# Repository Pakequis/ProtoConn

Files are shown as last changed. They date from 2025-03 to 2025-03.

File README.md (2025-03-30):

[][cc-by-sa]
# ProtoConn
A prototype board with connectors for electronic testing and development

This work is licensed under a
[Creative Commons Attribution-ShareAlike 4.0 International License][cc-by-sa].

[][cc-by-sa]

[cc-by-sa]: http://creativecommons.org/licenses/by-sa/4.0/
[cc-by-sa-image]: https://licensebuttons.net/l/by-sa/4.0/88x31.png
[cc-by-sa-shield]: https://img.shields.io/badge/License-CC%20BY--SA%204.0-lightgrey.svg

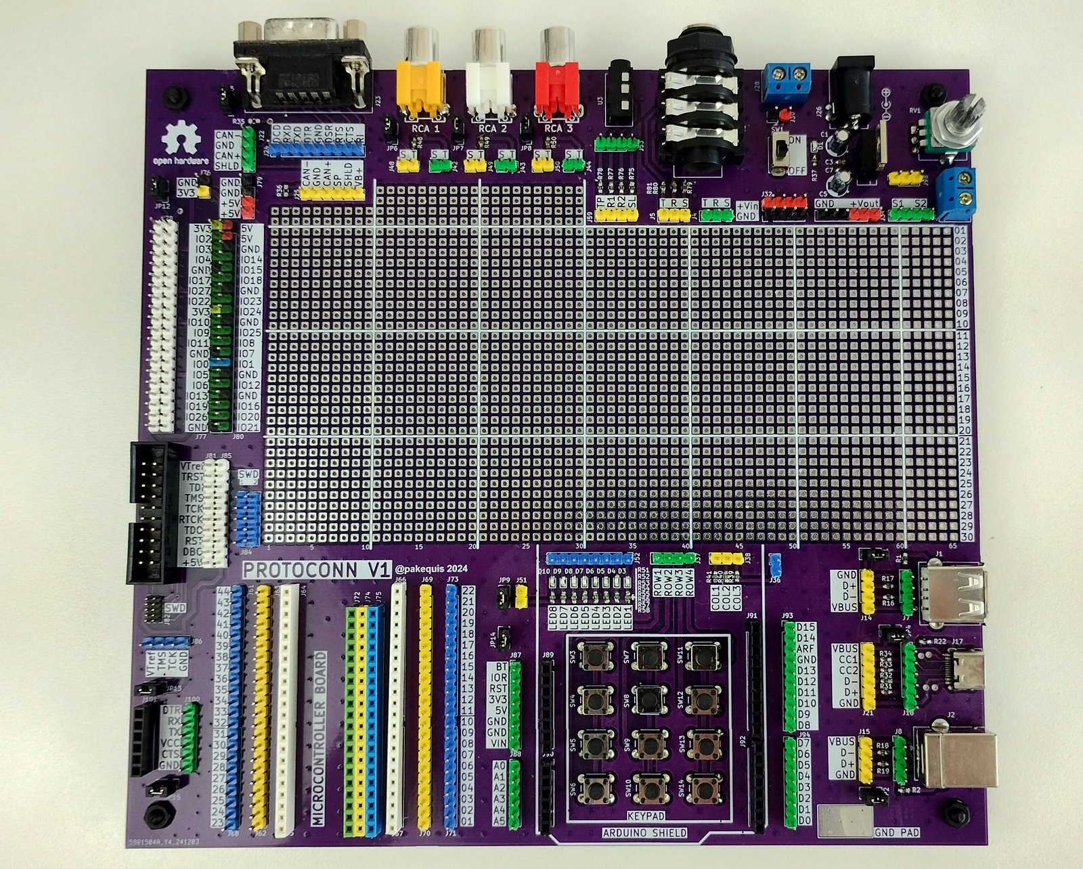
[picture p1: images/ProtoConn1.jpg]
ProtoConn V1


### Overview

This open-hardware prototype board was created as a practical tool to simplify and speed up prototyping. With connectors for various functions, it’s designed to make development more flexible and efficient.

## Demo video:
Demo Video (https://www.youtube.com/watch?v=2lRD86RqEf8)

### Features

Size: 200 x 195 mm dual layer PCB.
- **DE-9 Connector**: Supports serial, joystick, or CAN communication.
- **RCA Connectors**: Includes 3 RCA connectors.
- **Audio Connectors**:
  - 1 P2 audio jack (up to 4 pins).
  - 1 6.3 mm audio jack.
- **Screw Terminals**: Includes 2 screw terminals, one dedicated to power supply.
- **Barrel Connector**: For power input, with integrated 78XX voltage regulator and on/off switch.
- **Potentiometer or Rotary Encoder**: For adjustable input functionality.
- **40-Pin I/O Connector**: Compatible with Raspberry Pi and other Single Board Computers (SBCs).
- **JTAG Connector**: Standard 20-pin JTAG interface.
- **SWD Connectors**:
  - 10-pin SWD with 2.54 mm pitch.
  - 10-pin SWD with 1.27 mm pitch.
- **Programming Connector**: 4-pin interface for STM32 programming.
- **USB/Serial Converter Connector**: Simplifies communication setup.
- **Microcontroller Spaces**: Dedicated spaces for microcontroller boards with widths of 600, 700, 800, and 1000 mils.
- **Arduino Shield Compatibility**: Area for connecting Arduino-compatible shields.
- **Matrix Keypad**: Includes a 12-key matrix keypad.
- **LED Indicators**: 8 LEDs with current-limiting resistors.
- **USB Connectors**:
  - 1 USB Type-A connector.
  - 1 USB Type-B connector.
  - 1 USB Type-C connector.
- **Ground Pad**: Convenient GND pad for prototyping needs.

### Project Files
All project files are organized in the `hardware` folder. If you'd like to manufacture an identical board, the Gerber files necessary for production are available in the `hardware/fab` folder.

Please note that the board does not need to be assembled exactly as shown in the photo. You are free to assemble only the components you want or need, tailoring it to your specific requirements.

Because of this flexibility, the project does not include a complete bill of materials (BOM). Please refer to the notes in the schematic diagram for more detailed information.

Below is an example of an assembled board featuring common black connectors:

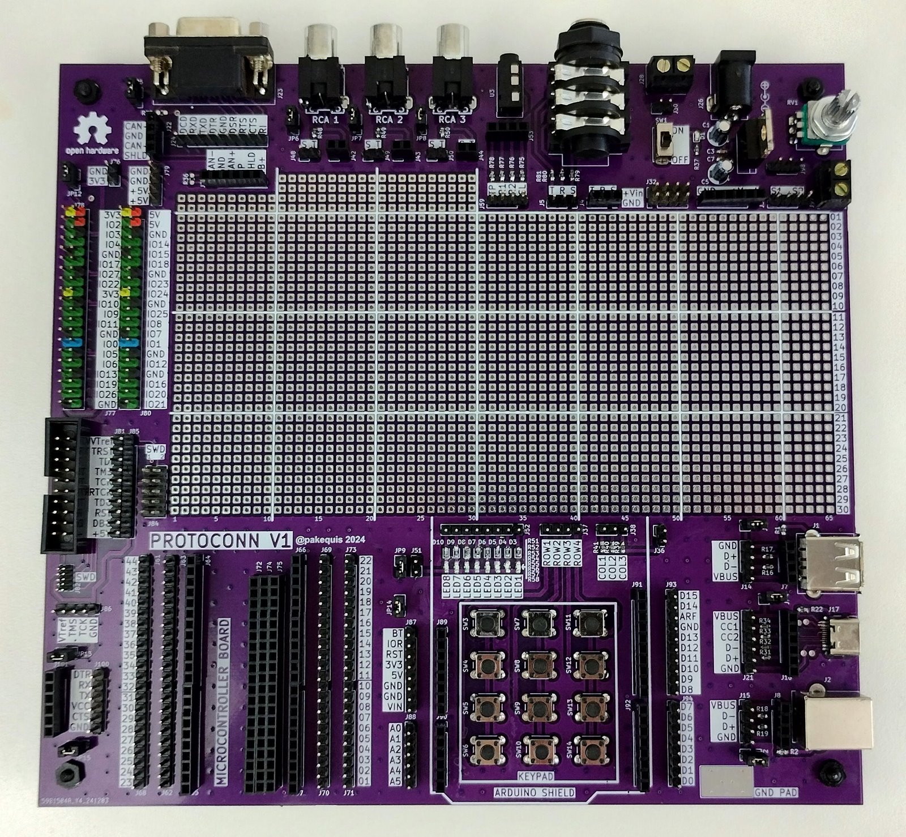
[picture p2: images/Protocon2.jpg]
Photo of the board with black connectors


## Recommended Components

Here are some specific components that can be used with this board, along with links to purchase them:

- **Colorful Breakable Pin Header 2.54mm Single Row Male**: [Aliexpress](https://s.click.aliexpress.com/e/_op1UJvb)
- **Colorful Breakable Pin Header 2.54mm Single Row Female**: [Aliexpress](https://s.click.aliexpress.com/e/_oB8GhPJ)
- **40-Pin Header for Raspberry Pi**: [Aliexpress](https://s.click.aliexpress.com/e/_oCoQNaN)
- **USB Type-C 02 Connector**: [Aliexpress](https://s.click.aliexpress.com/e/_oo63JmH)
- **Power switch**: [Aliexpress](https://s.click.aliexpress.com/e/_oD5kKvX)

The other components are common and easy to find.

**Affiliate Disclosure**: Some of the links provided in this section are affiliate links. This means that I may earn a commission if you make a purchase through these links, at no additional cost to you. Your support helps to maintain and improve this project.

### Connector Areas

Below are images showcasing the connector areas of the board:

### Top Connector Area
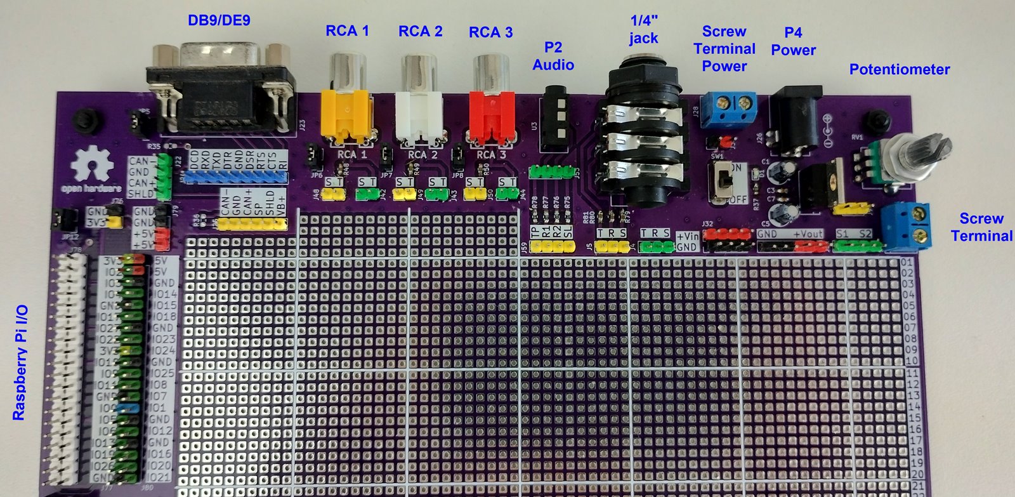
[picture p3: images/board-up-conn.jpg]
Photo of the top connector area


### Bottom Connector Area
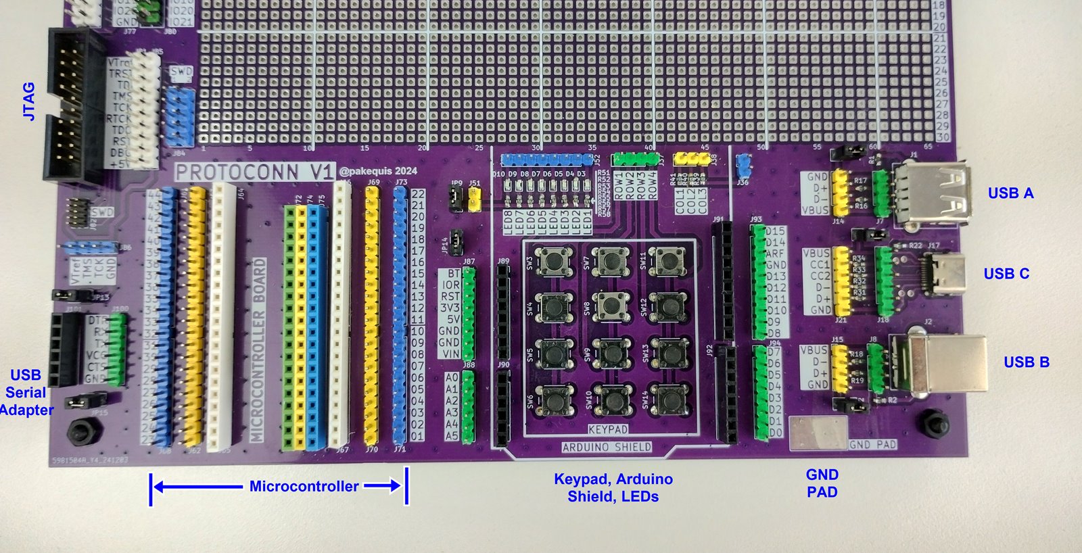
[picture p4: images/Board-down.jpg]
Photo of the bottom connector area


### Project Background:
Almost 20 years ago, I purchased a commercial prototype board with multiple connectors that greatly facilitated my work. Unfortunately, I no longer remember where I bought it, and I am unsure if it is still being manufactured. This inspired me to create my own version, customized to meet my specific needs.

The board (circa 2008):
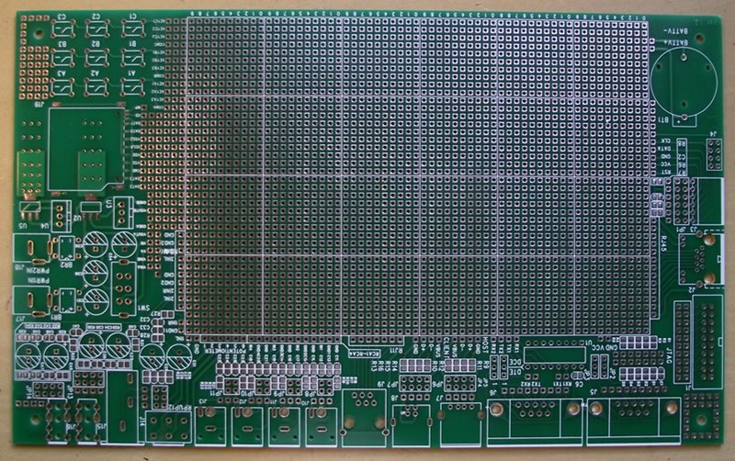
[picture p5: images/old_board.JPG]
Photo of the original commercial board


## Contact:

Feel free to reach out to me on social media: @pakequis in any of them...

You can also send me an email at pakequis (Gmail).

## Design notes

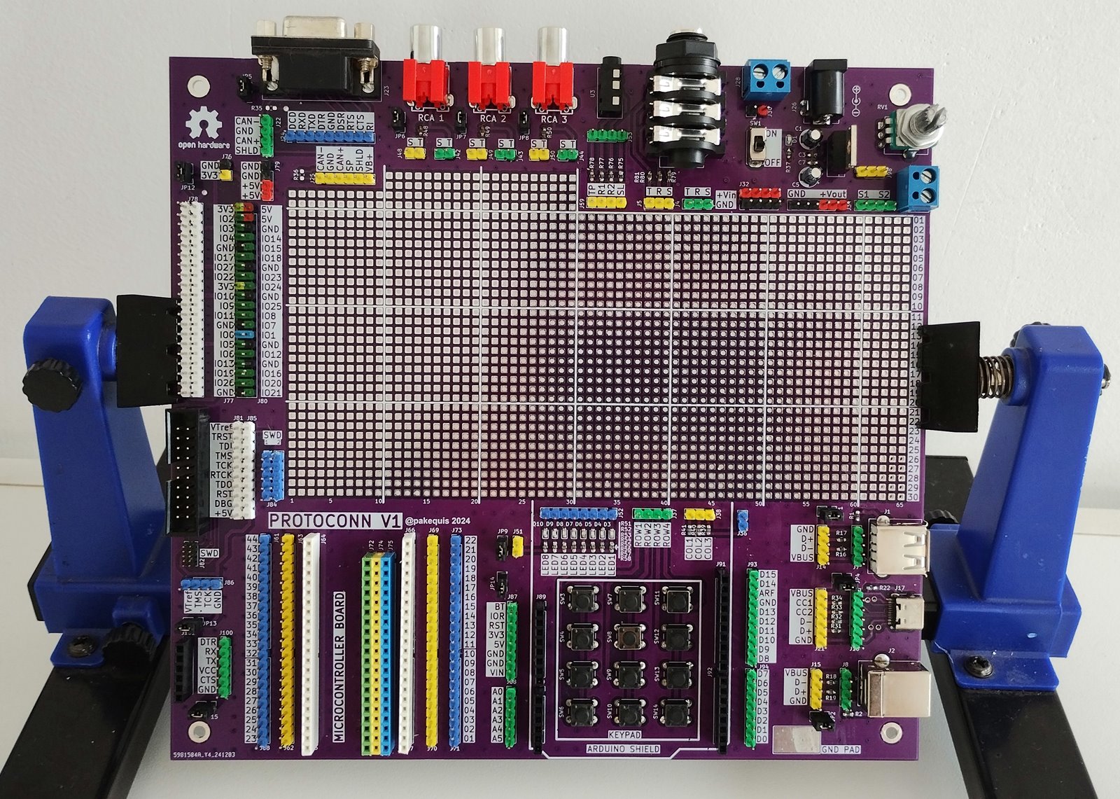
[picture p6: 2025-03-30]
images/Protoconn_V1.jpg

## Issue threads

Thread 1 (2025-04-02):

Soldering jig for ProtoConn

shreekumar3d, 2025-04-02:
I have created a [tool that generates soldering jigs](https://github.com/shreekumar3d/jigita) directly from KiCAD files. As a test for my tool, I ran it against ProtoConn PCB design and got good initial results.  The tool creates this workflow:

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

The orange part is the jig (3D printable design). With the jig in hand, you first insert the components into the holders in the jig. Then you insert the PCB, and solder the components. Then you pull out the assembled PCB.  I have documented this a bit more [at this page](https://github.com/shreekumar3d/jigita/tree/main/demo/06-lots-of-connectors). There you'll find the jig and a FreeCAD test file as well.

Hoping you may find the tool useful.  It probably needs some tweaks to make it usable. Comments welcome; happy to answer any queries.

Pakequis, 2025-04-03:
Thanks a lot for pitching in and helping out with this project! I'm really grateful for your contribution. In the next update of the README, I'll make sure to add a link to this project. Thanks again for your support!

Closed 2025-04-03.

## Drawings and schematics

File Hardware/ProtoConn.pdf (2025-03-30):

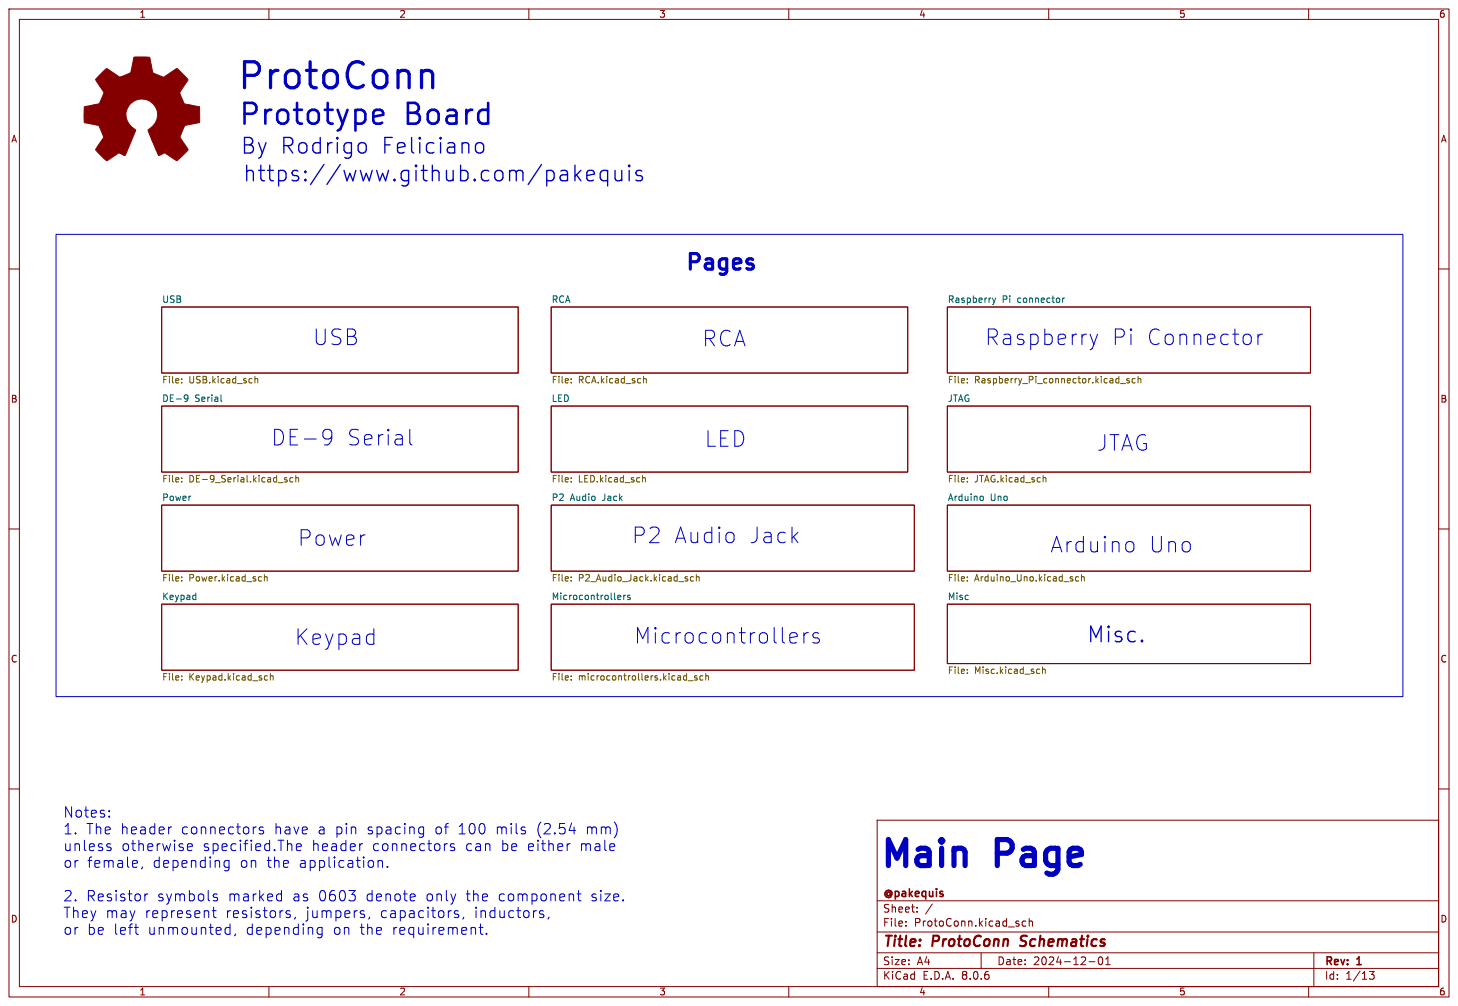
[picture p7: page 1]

ProtoConn
By Rodrigo Feliciano
https://www.github.com/pakequis

File: USB.kicad_sch Keypad File: Keypad.kicad_sch

Notes:
or female, depending on the application.

Id: 1/13 Title: ProtoConn Schematics

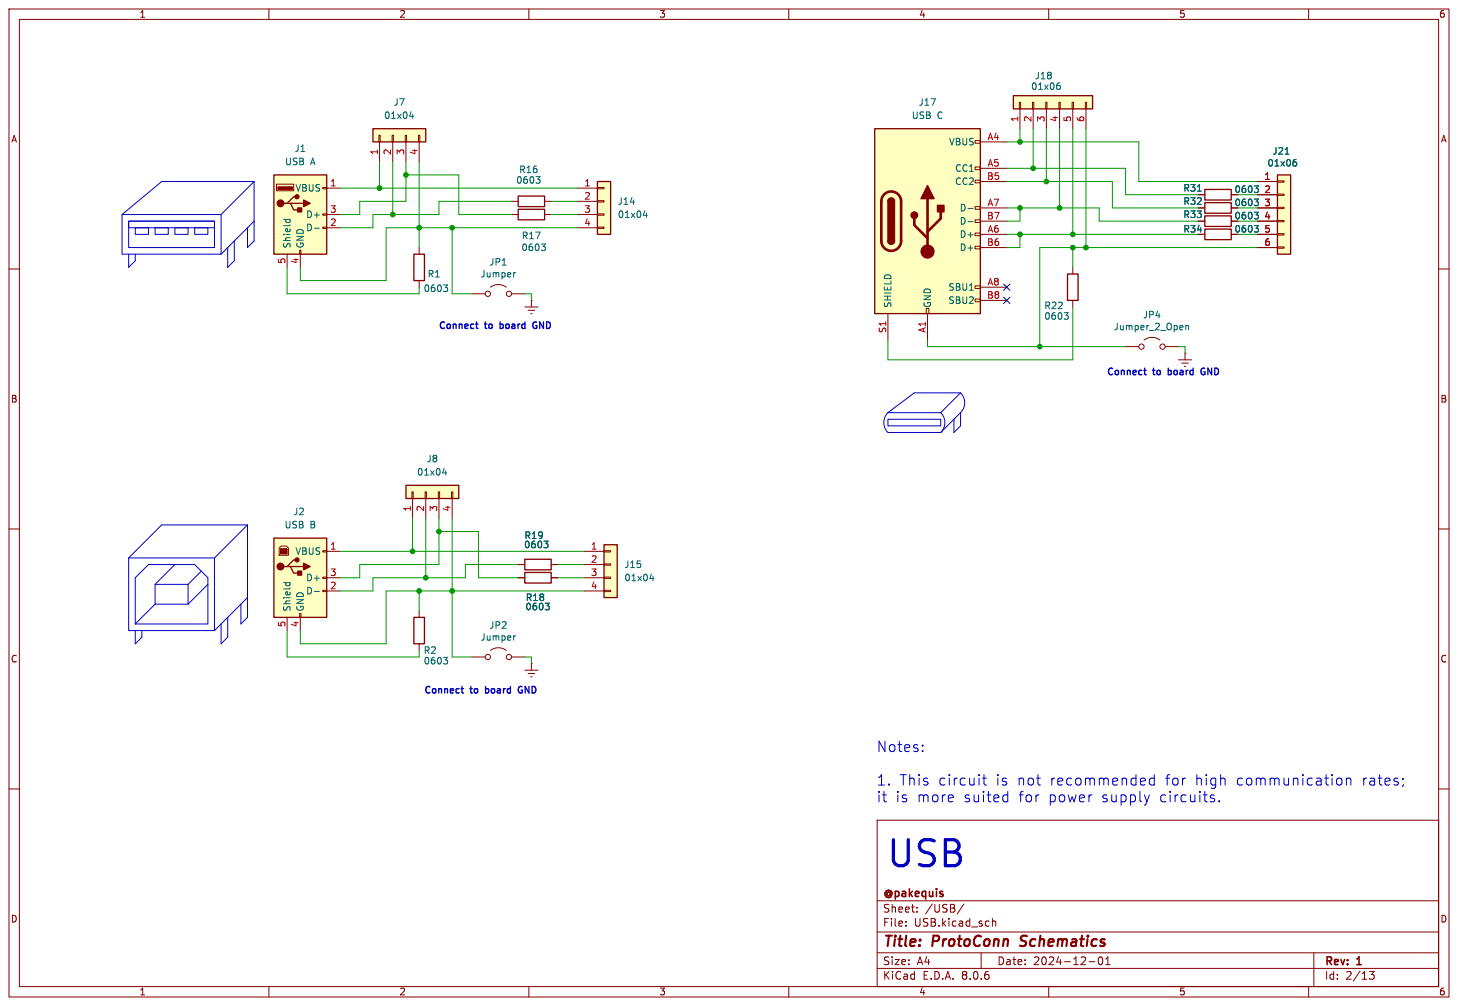
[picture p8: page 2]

Connect to board GND

File: USB.kicad_sch Sheet: /USB/ @pakequis

Id: 2/13 Title: ProtoConn Schematics

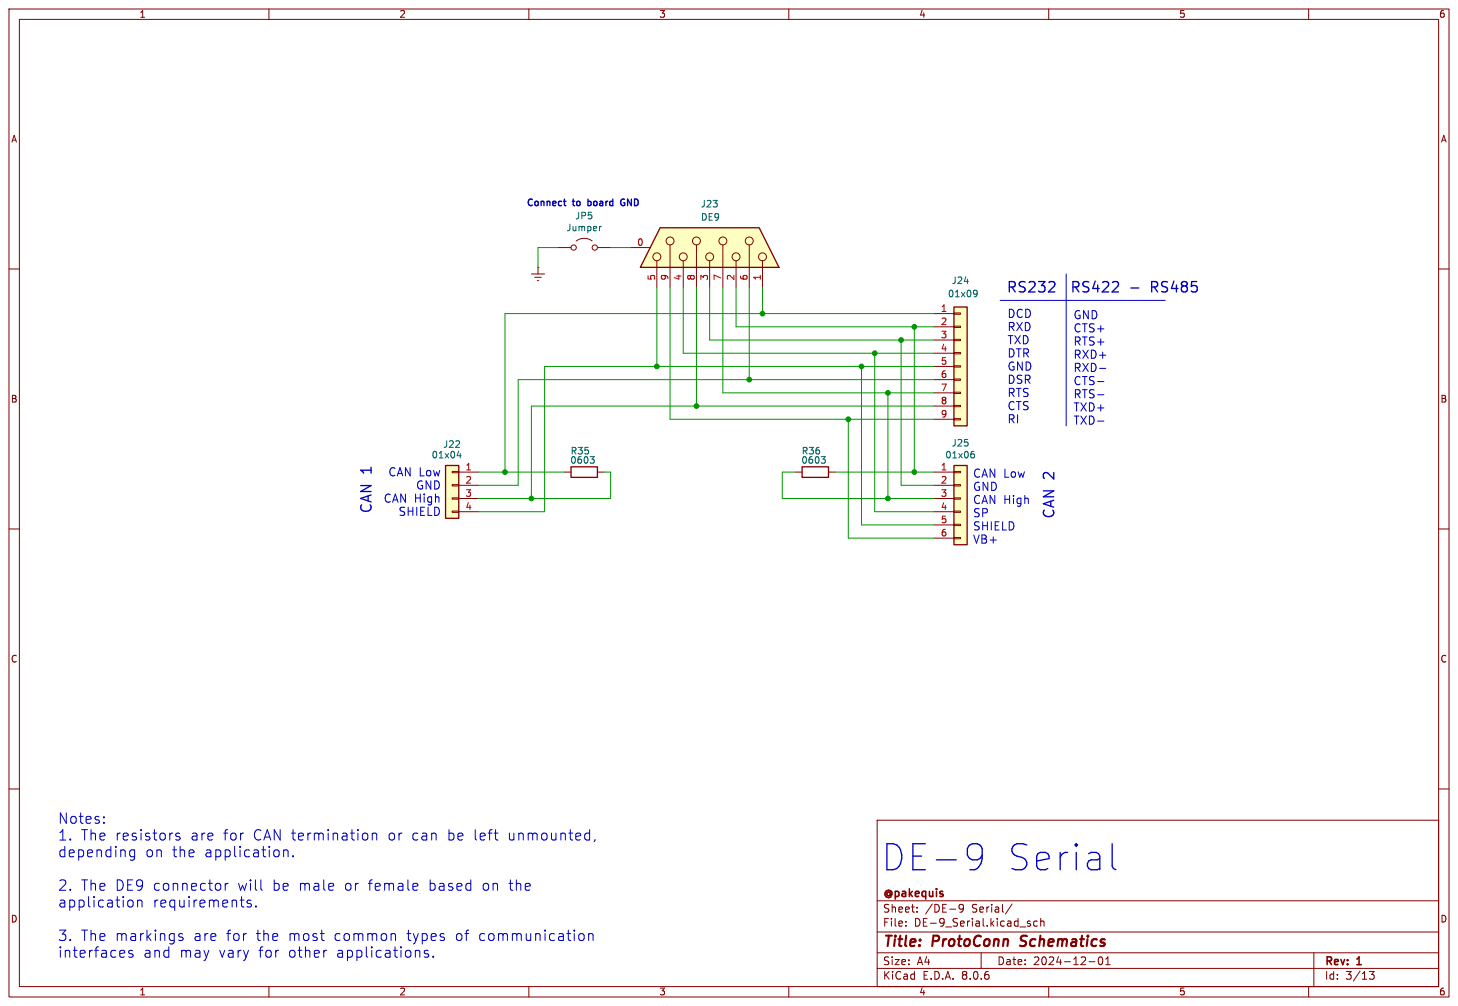
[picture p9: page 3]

RTS- TXD+ TXD- DE-9 Serial

CTS+
RTS+ RXD+ RXD- CTS-

Id: 3/13 Title: ProtoConn Schematics

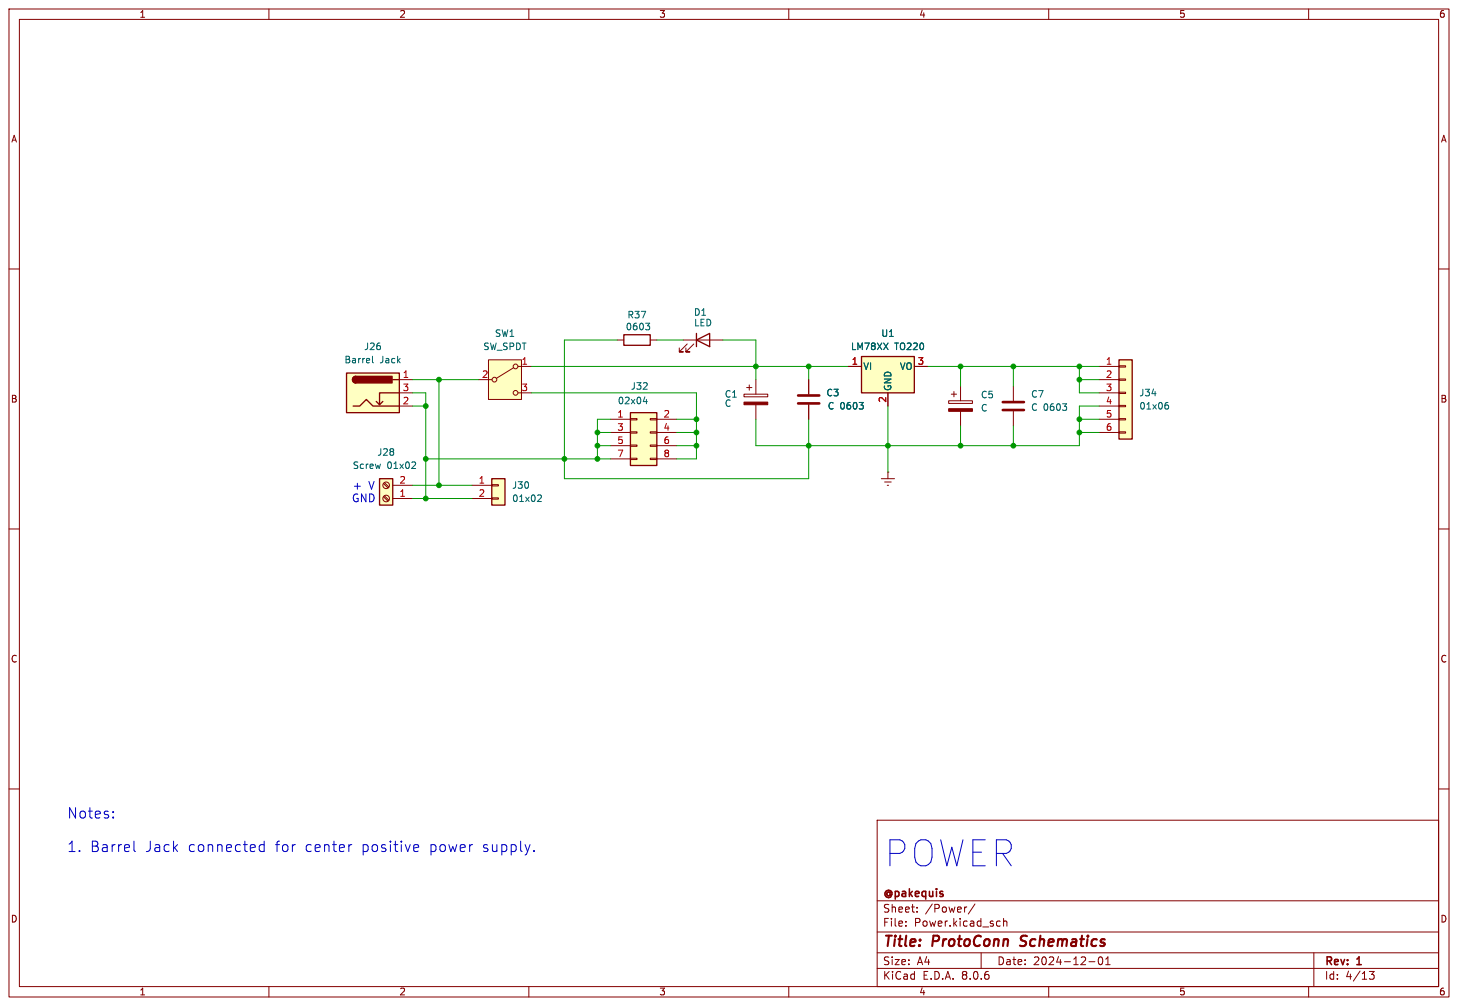
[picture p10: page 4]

File: Power.kicad_sch Sheet: /Power/ @pakequis

Id: 4/13 Title: ProtoConn Schematics

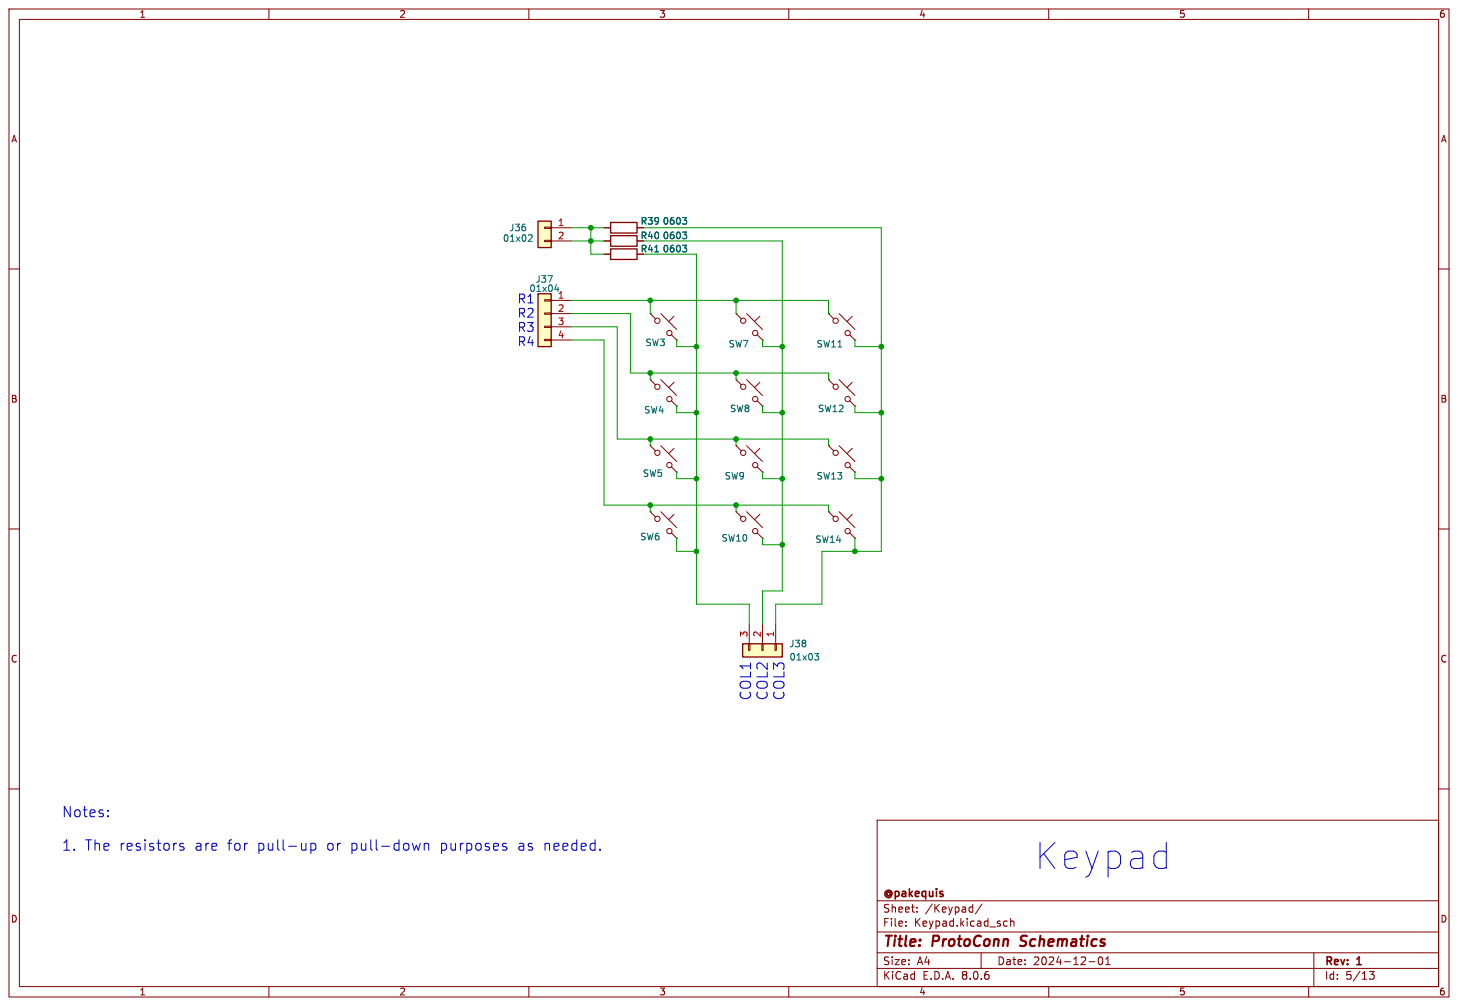
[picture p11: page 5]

@pakequis
File: Keypad.kicad_sch Sheet: /Keypad/
Id: 5/13 Title: ProtoConn Schematics

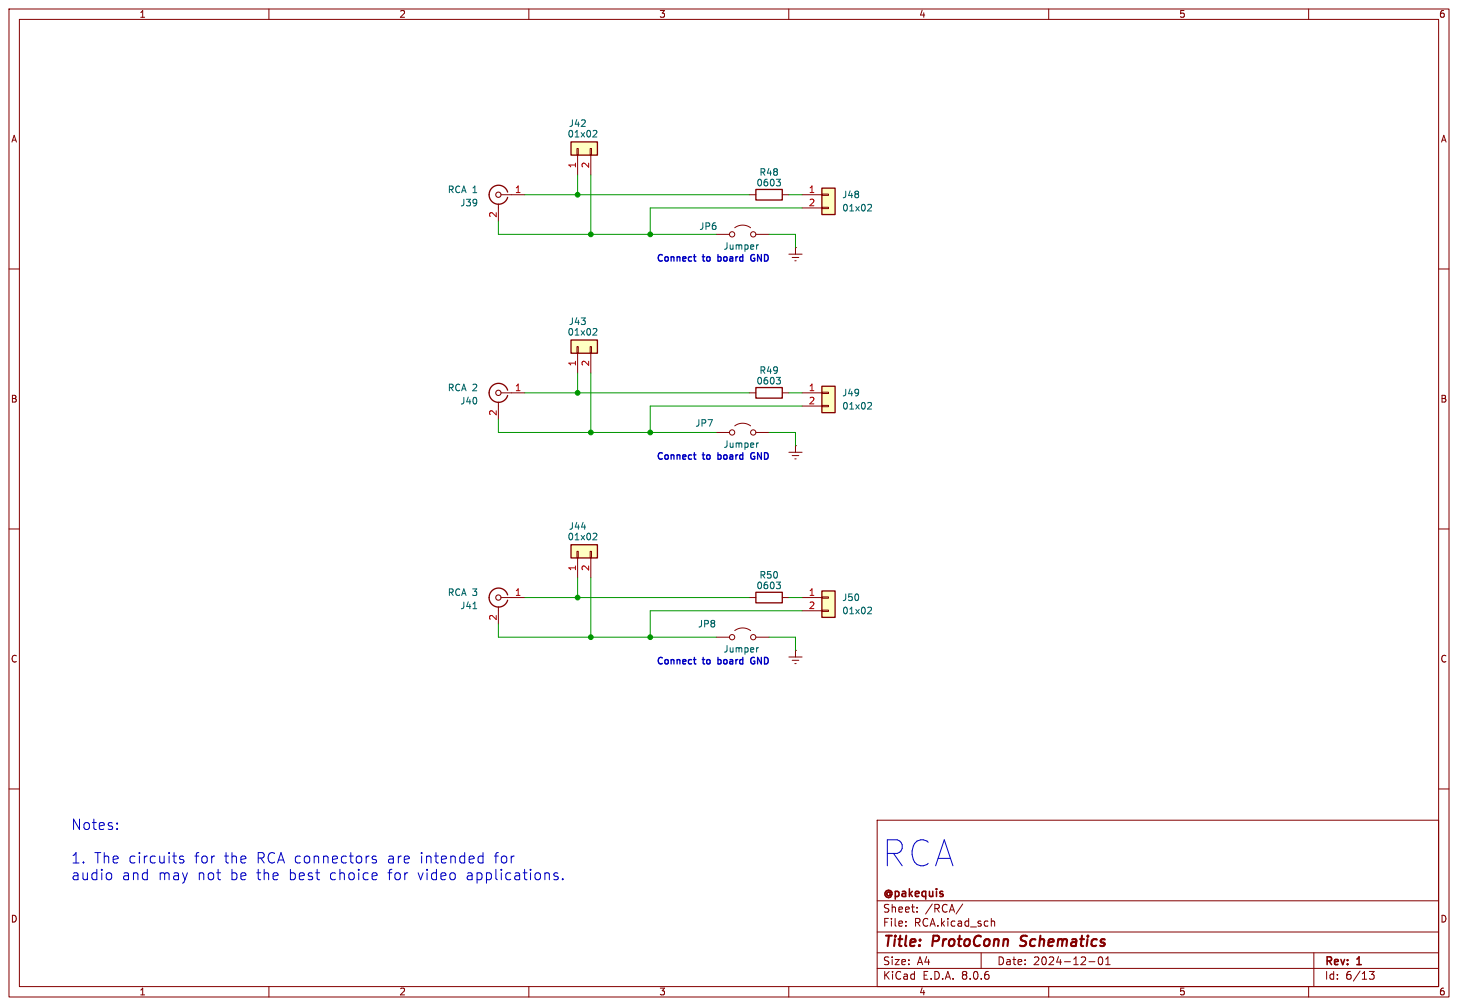
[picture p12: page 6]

Connect to board GND

Connect to board GND Notes:

File: RCA.kicad_sch Sheet: /RCA/ @pakequis

Id: 6/13 Title: ProtoConn Schematics

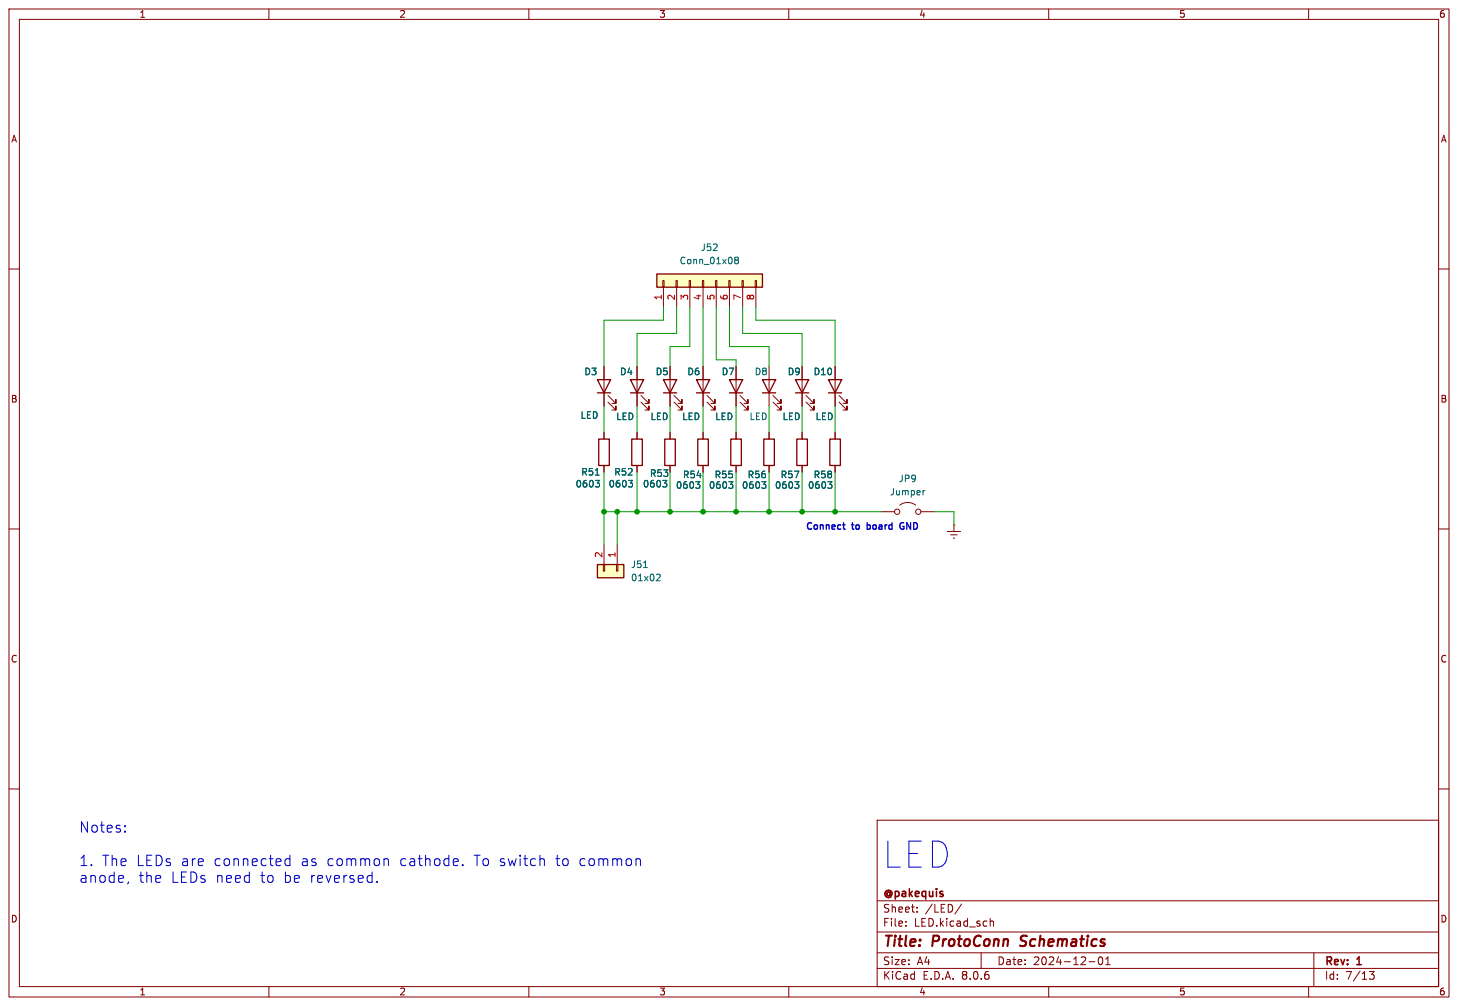
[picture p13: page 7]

Connect to board GND

File: LED.kicad_sch Sheet: /LED/ @pakequis

Id: 7/13 Title: ProtoConn Schematics

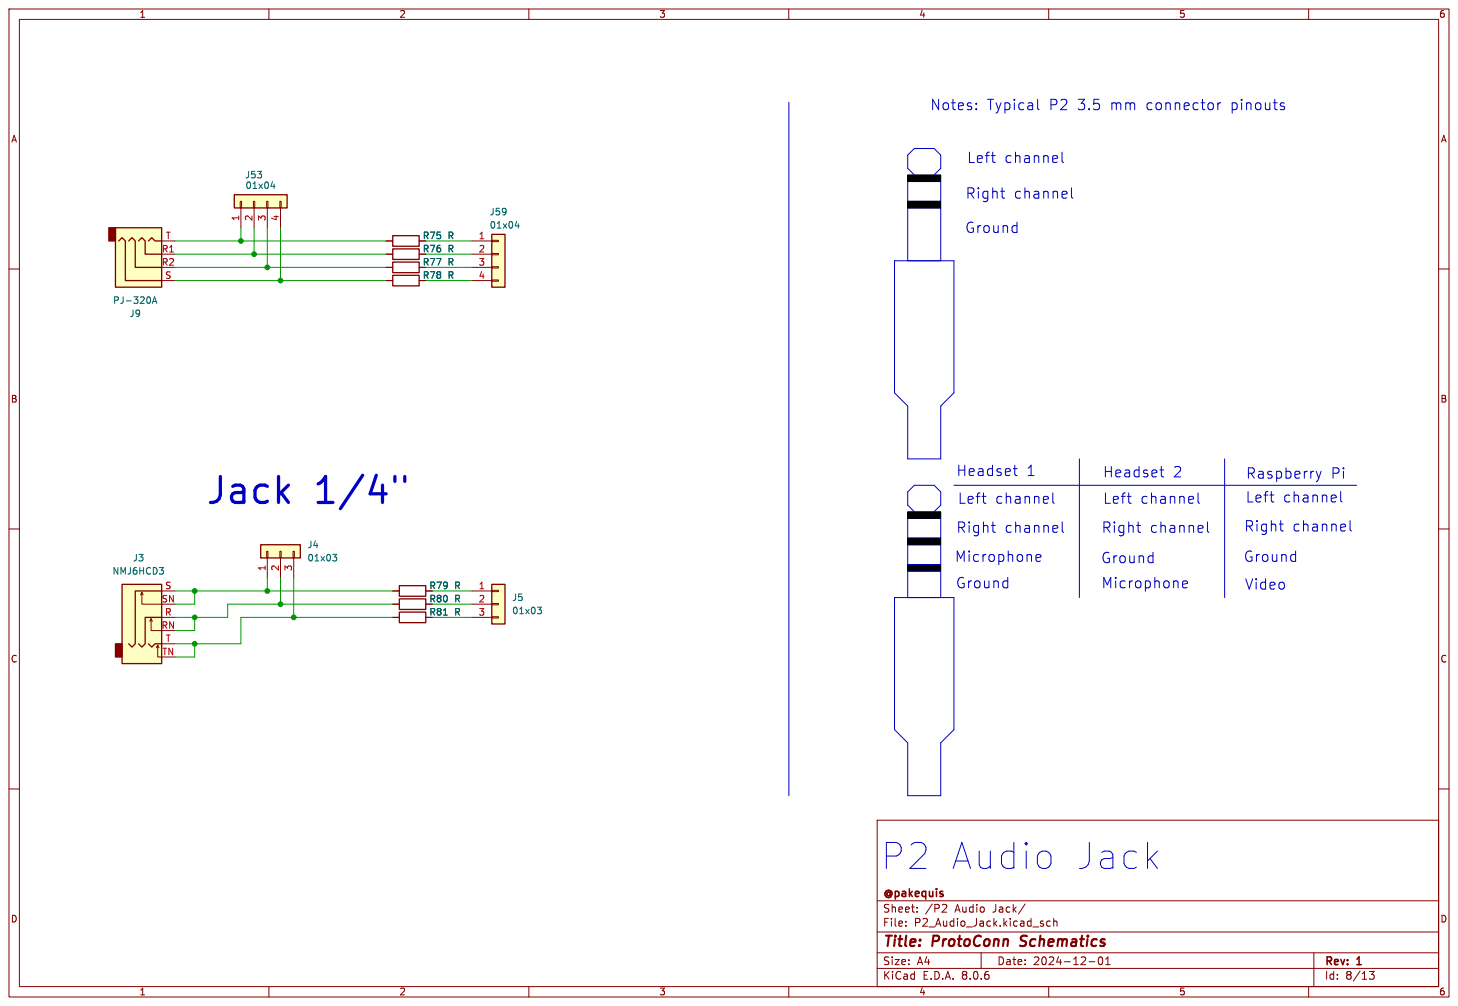
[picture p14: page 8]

Id: 8/13 Title: ProtoConn Schematics

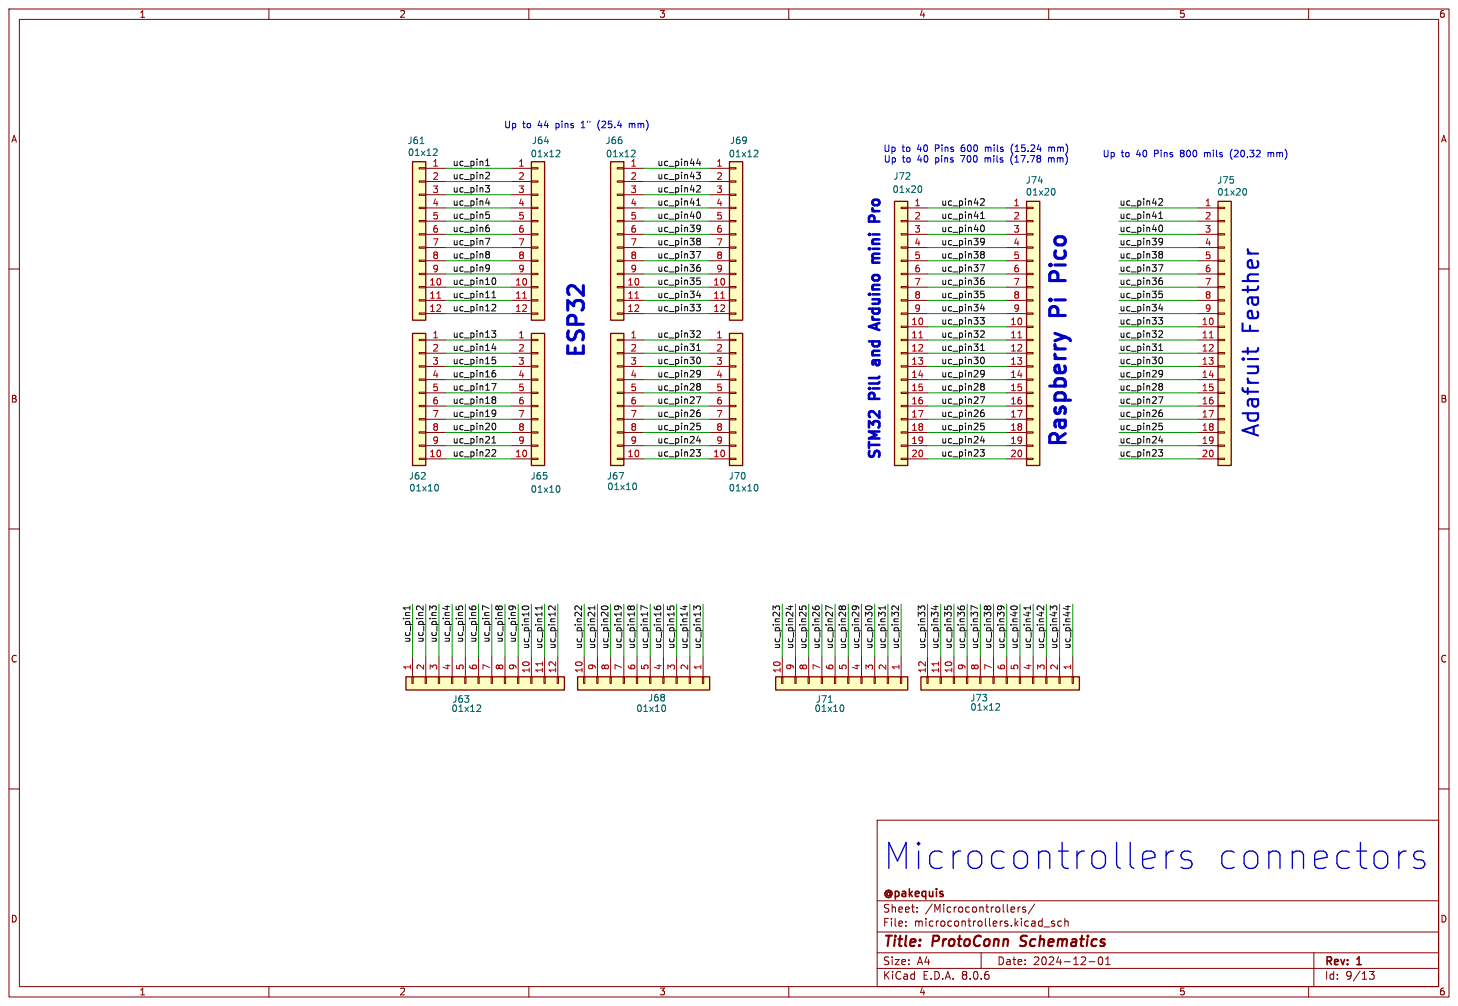
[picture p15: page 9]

File: microcontrollers.kicad_sch Sheet: /Microcontrollers/ @pakequis

Id: 9/13 Title: ProtoConn Schematics

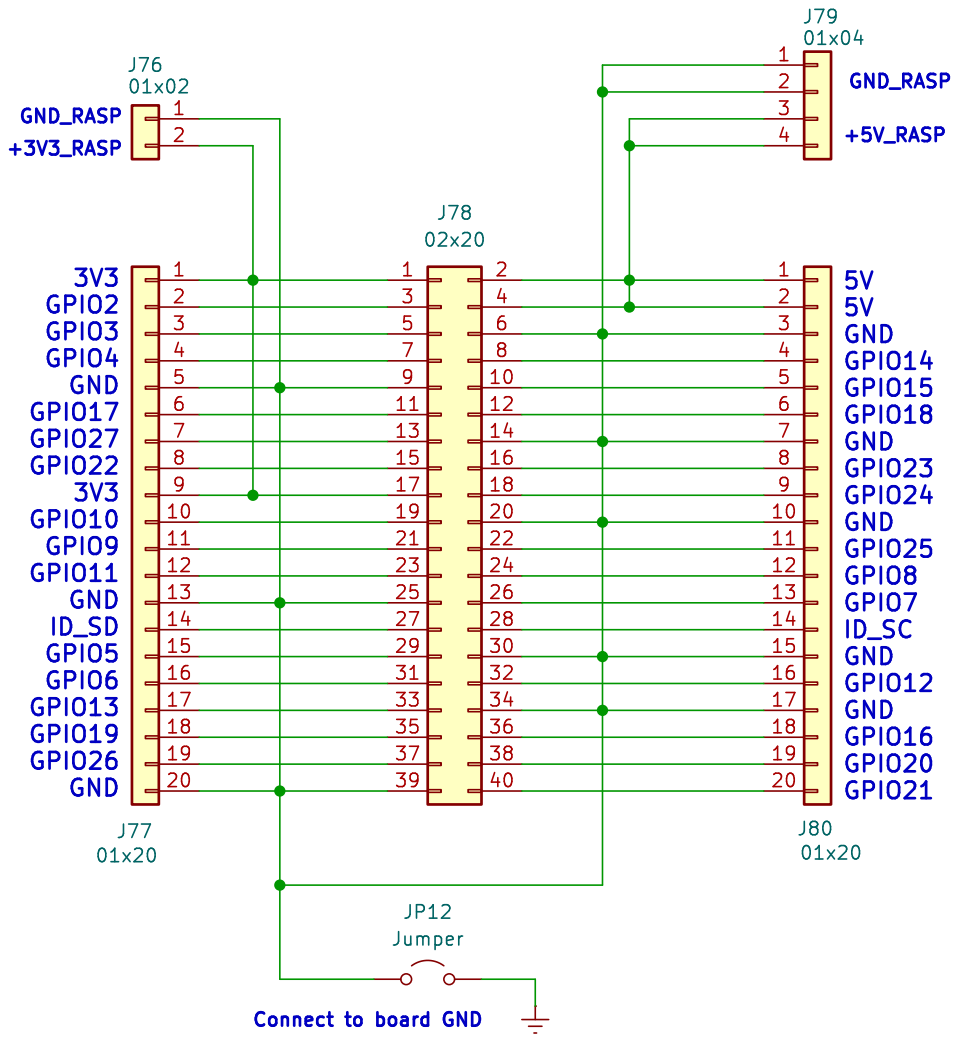
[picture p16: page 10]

Connect to board GND GND_RASP
+5V_RASP 3V3

Id: 10/13 Title: ProtoConn Schematics

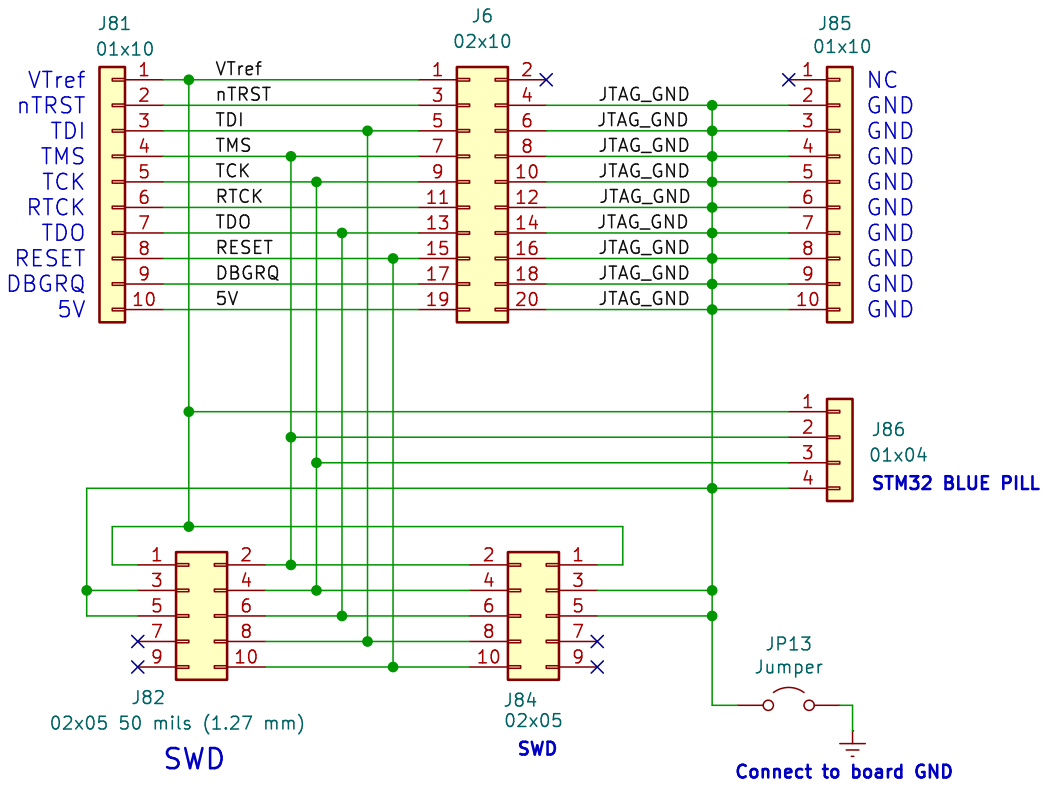
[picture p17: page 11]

4 | | 7 | | JTAG_GND VTref 8 JTAG_GND | 4

3 | 5 | | JTAG_GND 6 | 3

5 | | | 9 | | 10 | 5
6 | RTCK | | | 11 | | 12 JTAG_GND | 6
7 | TDO | | | 13 | | 14 JTAG_GND | 7
9 | 5VRESET DBGRQ | | | | | 17 | | 18 JTAG_GND | 9
8 | | | | | 15 | | 16 | 8

10 | | | | | | 19 | | 20 JTAG_GND | 10

File: JTAG.kicad_sch Sheet: /JTAG/ @pakequis

Id: 11/13 Title: ProtoConn Schematics

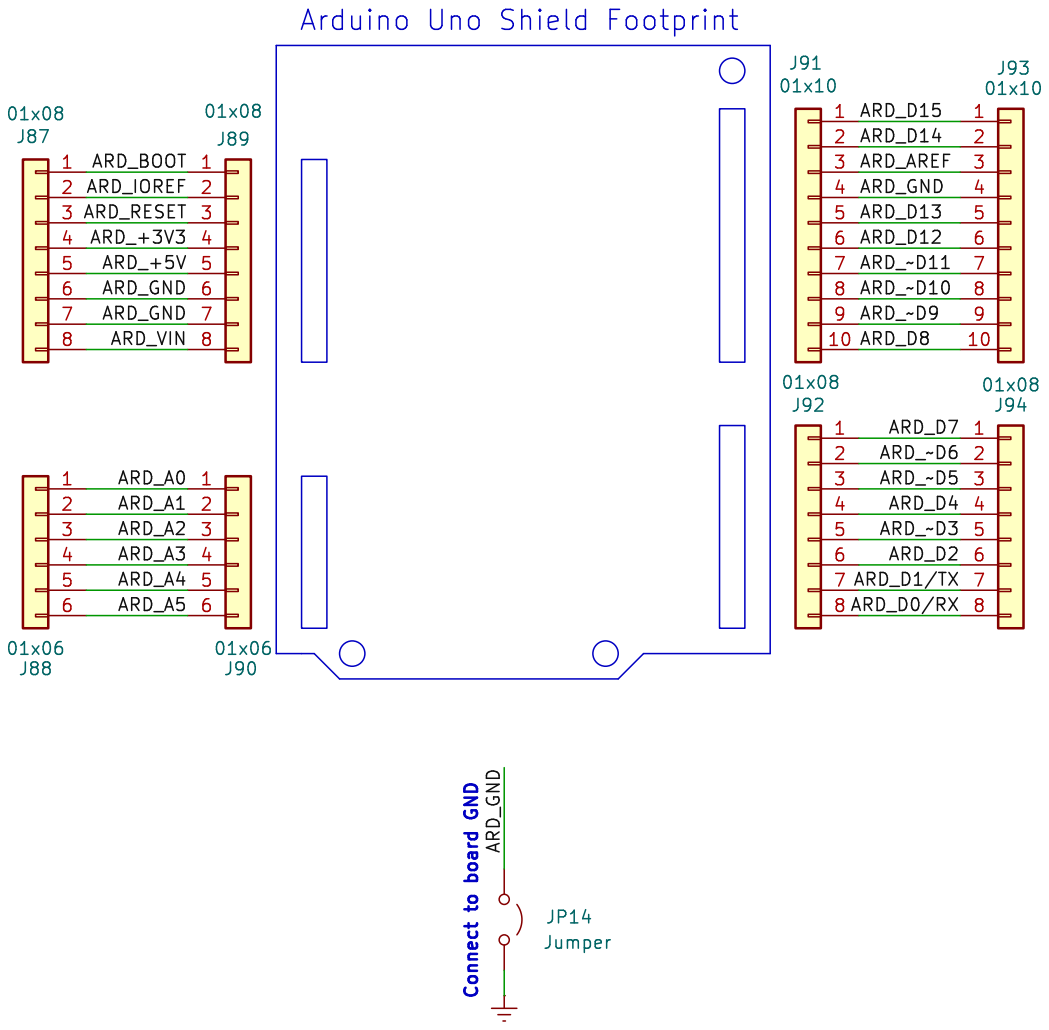
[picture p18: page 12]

ARD_~D3 ARD_D4 ARD_~D11 ARD_D13 ARD_~D9 ARD_~D10 ARD_AREF ARD_D12 ARD_D14 Connect to board GND

Id: 12/13 Title: ProtoConn Schematics


File: Misc.kicad_sch Sheet: /Misc/ @pakequis

Id: 13/13 Title: ProtoConn Schematics

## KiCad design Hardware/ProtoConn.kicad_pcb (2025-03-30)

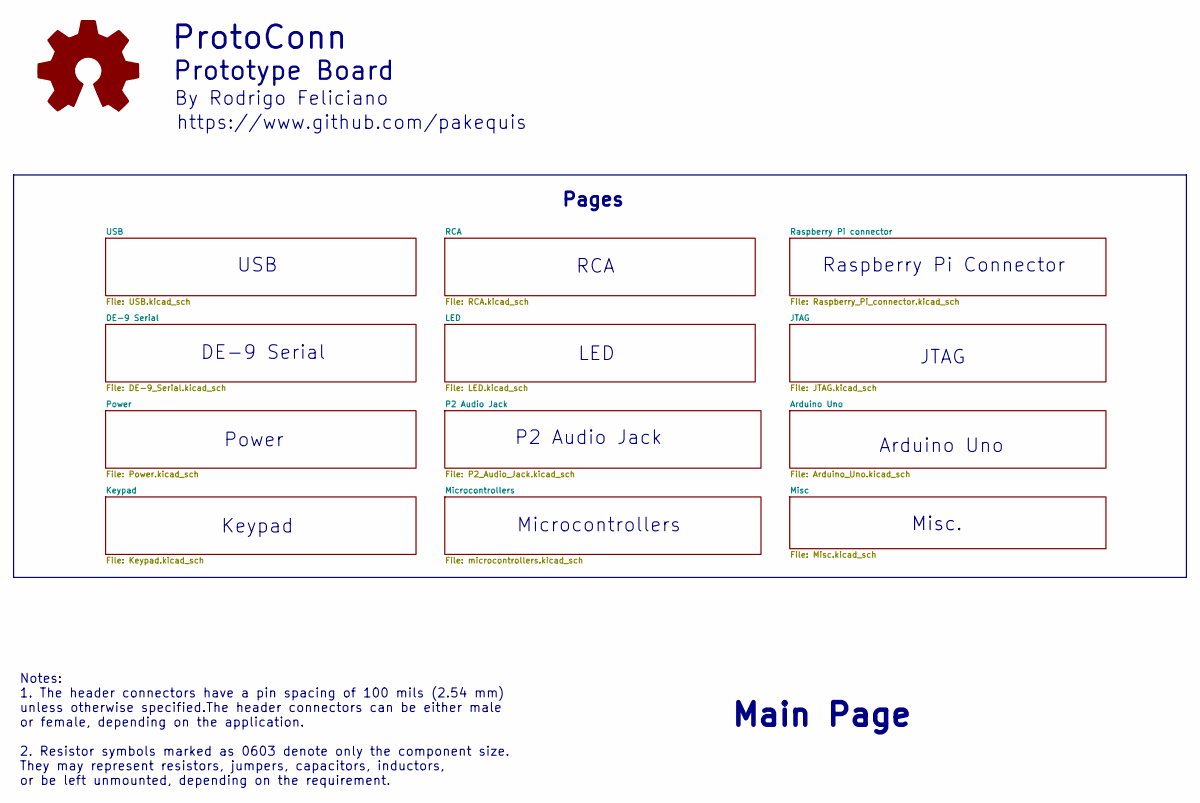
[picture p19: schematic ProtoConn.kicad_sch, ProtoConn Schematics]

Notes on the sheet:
USB
Main Page
P2 Audio Jack
Arduino Uno
Microcontrollers
Notes: 1. The header connectors have a pin spacing of 100 mils (2.54 mm) unless otherwise specified.The header connectors can be either male or female, depending on the application. 2. Resistor symbols marked as 0603 denote only the component size. They may represent resistors, jumpers, capacitors,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
Pages
Raspberry Pi Connector
https://www.github.com/pakequis
RCA
Power
JTAG
Keypad
DE-9 Serial
Misc.
LED
Prototype Board
ProtoConn
By Rodrigo Feliciano

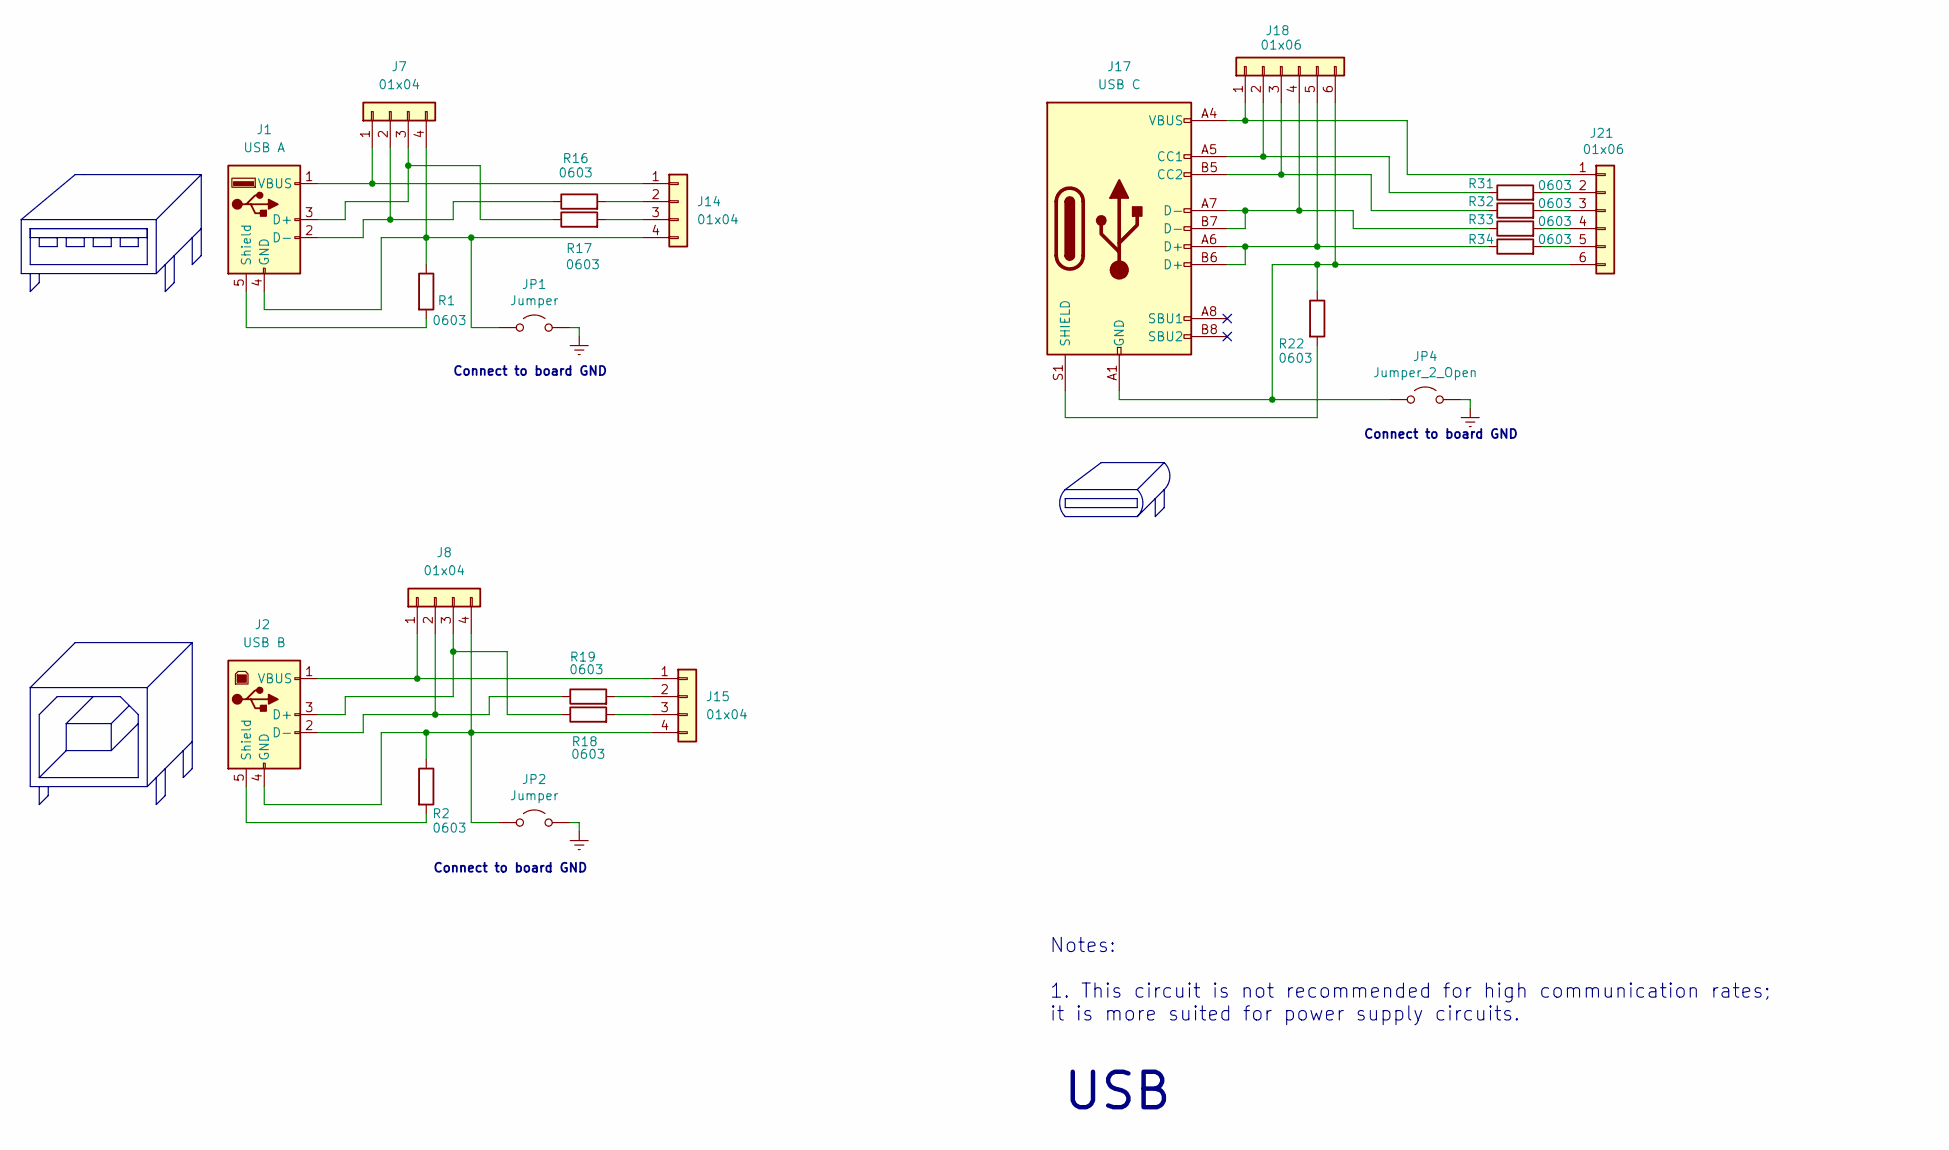
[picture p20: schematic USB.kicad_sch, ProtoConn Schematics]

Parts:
J1: USB A; USB_A_CONNFLY_DS1095-WNR0
J2: USB B; USB_B_Lumberg_2411_02_Horizontal
J7, J8, J14, J15: 01x04; PinHeader_1x04_P2.54mm_Vertical
J17: USB C; USB_C_Receptacle_HRO_TYPE-C-31-M-12
J18, J21: 01x06; PinHeader_1x06_P2.54mm_Vertical
JP1, JP2: Jumper; PinHeader_1x02_P2.54mm_Vertical
JP4: Jumper_2_Open; PinHeader_1x02_P2.54mm_Vertical
R1, R2, R16, R17, R18, R19, R22, R31, R32, R33, R34: 0603; R_0603_1608Metric_Pad0.98x0.95mm_HandSolder

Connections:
GNDREF: JP1.1 (A), JP2.1 (A), JP4.1 (A); also elsewhere on the board
unnamed: J1.3 (D+), J7.3, R17.1
unnamed: J1.2 (D-), J7.2, R16.1
unnamed: J1.4 (GND), J7.4, J14.4, JP1.2 (B), R1.1
unnamed: J1.5 (Shield), R1.2
unnamed: J1.1 (VBUS), J7.1, J14.1
unnamed: J2.3 (D+), J8.3, R19.1
unnamed: J2.2 (D-), J8.2, R18.1
unnamed: J2.5 (Shield), R2.2
unnamed: J14.2, R16.2
unnamed: J14.3, R17.2
unnamed: J2.1 (VBUS), J8.1, J15.1
unnamed: J15.2, R18.2
unnamed: J15.3, R19.2
unnamed: J2.4 (GND), J8.4, J15.4, JP2.2 (B), R2.1
unnamed: J17.A5 (CC1), J18.2, R31.1
unnamed: J17.B5 (CC2), J18.3, R32.1
unnamed: J17.S1 (SHIELD), R22.2
unnamed: J17.A4 (VBUS), J17.A9 (VBUS), J17.B4 (VBUS), J17.B9 (VBUS), J18.1, J21.1
unnamed: J17.A7 (D-), J17.B7 (D-), J18.4, R33.1
unnamed: J17.A6 (D+), J17.B6 (D+), J18.5, R34.1
unnamed: J17.A1 (GND), J17.A12 (GND), J17.B1 (GND), J17.B12 (GND), J18.6, J21.6, JP4.2 (B), R22.1
unnamed: J21.2, R31.2
unnamed: J21.3, R32.2
unnamed: J21.4, R33.2
unnamed: J21.5, R34.2

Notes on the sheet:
Connect to board GND
Notes: 1. This circuit is not recommended for high communication rates; it is more suited for power supply circuits.
USB

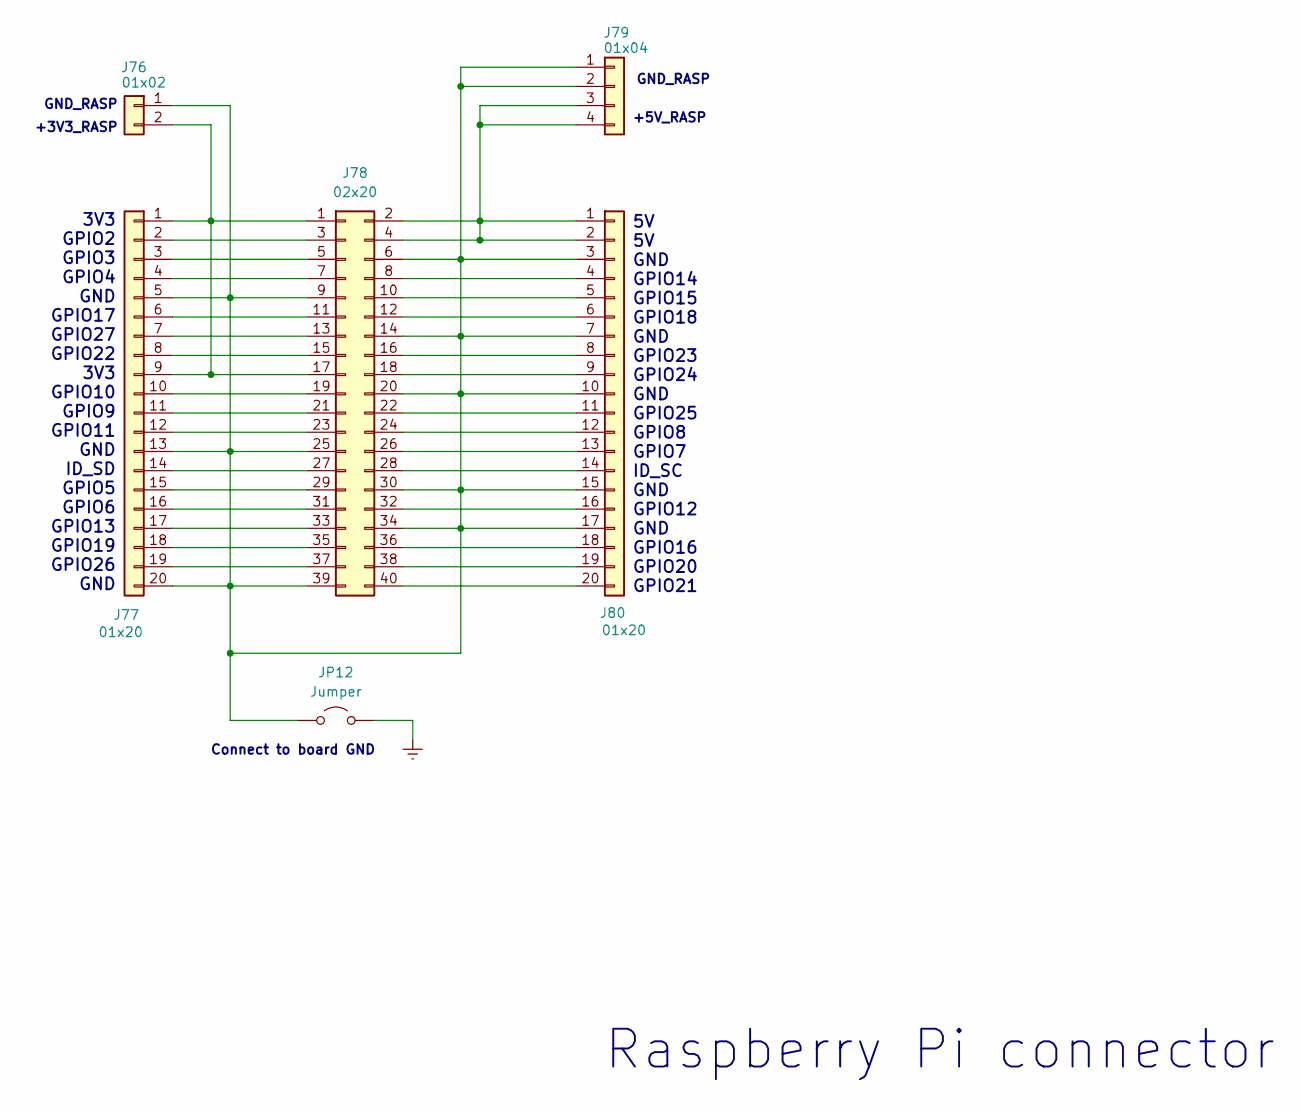
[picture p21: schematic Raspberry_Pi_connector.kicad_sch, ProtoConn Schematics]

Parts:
J76: 01x02; PinHeader_1x02_P2.54mm_Vertical
J77, J80: 01x20; PinHeader_1x20_P2.54mm_Vertical
J78: 02x20; PinHeader_2x20_P2.54mm_Vertical
J79: 01x04; PinHeader_1x04_P2.54mm_Vertical
JP12: Jumper; PinHeader_1x02_P2.54mm_Vertical

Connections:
GNDREF: JP12.2 (B); also elsewhere on the board
unnamed: J76.1, J77.5, J77.13, J77.20, J78.6, J78.9, J78.14, J78.20, J78.25, J78.30, J78.34, J78.39, J79.1, J79.2, J80.3, J80.7, J80.10, J80.15, J80.17, JP12.1 (A)
unnamed: J76.2, J77.1, J77.9, J78.1, J78.17
unnamed: J77.2, J78.3
unnamed: J77.3, J78.5
unnamed: J77.4, J78.7
unnamed: J77.6, J78.11
unnamed: J77.7, J78.13
unnamed: J77.8, J78.15
unnamed: J77.10, J78.19
unnamed: J77.11, J78.21
unnamed: J77.12, J78.23
unnamed: J77.14, J78.27
unnamed: J77.15, J78.29
unnamed: J77.16, J78.31
unnamed: J77.17, J78.33
unnamed: J77.18, J78.35
unnamed: J77.19, J78.37
unnamed: J78.2, J78.4, J79.3, J79.4, J80.1, J80.2
unnamed: J78.8, J80.4
unnamed: J78.10, J80.5
unnamed: J78.12, J80.6
unnamed: J78.16, J80.8
unnamed: J78.18, J80.9
unnamed: J78.22, J80.11
unnamed: J78.24, J80.12
unnamed: J78.26, J80.13
unnamed: J78.28, J80.14
unnamed: J78.32, J80.16
unnamed: J78.36, J80.18
unnamed: J78.38, J80.19
unnamed: J78.40, J80.20

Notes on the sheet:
3V3 GPIO2 GPIO3 GPIO4 GND GPIO17 GPIO27 GPIO22 3V3 GPIO10 GPIO9 GPIO11 GND ID_SD GPIO5 GPIO6 GPIO13 GPIO19 GPIO26 GND
GND_RASP
5V 5V GND GPIO14 GPIO15 GPIO18 GND GPIO23 GPIO24 GND GPIO25 GPIO8 GPIO7 ID_SC GND GPIO12 GND GPIO16 GPIO20 GPIO21
Connect to board GND
Raspberry Pi connector
+3V3_RASP
+5V_RASP

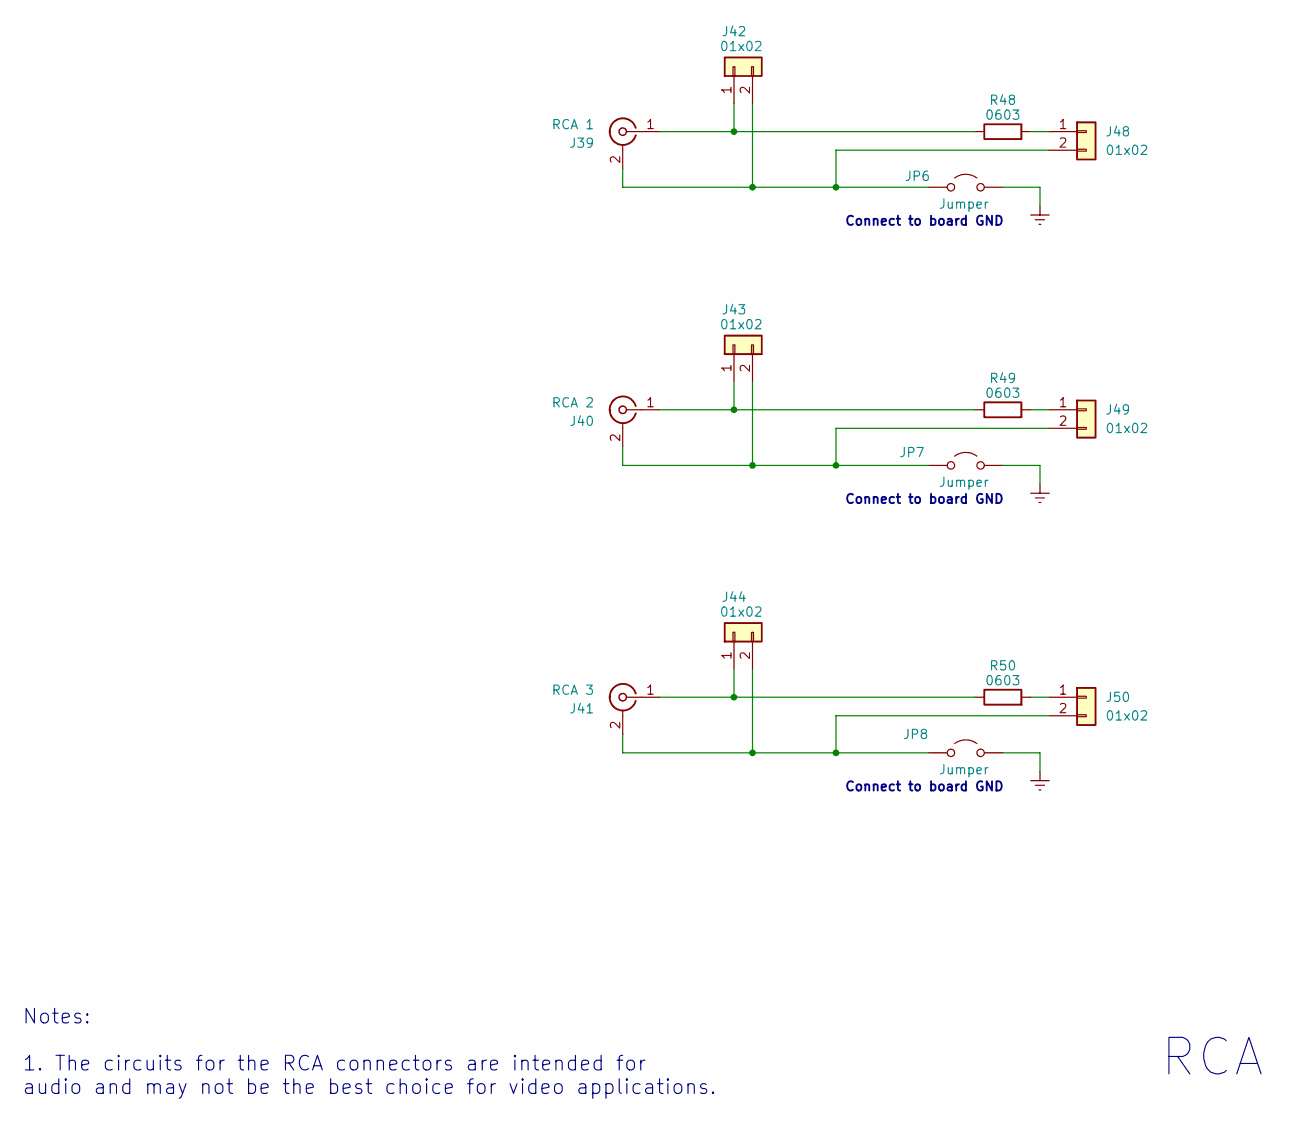
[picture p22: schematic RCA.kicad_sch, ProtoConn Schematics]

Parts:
J39: RCA 1; RCA-105-105A
J40: RCA 2; RCA-105-105A
J41: RCA 3; RCA-105-105A
J42, J43, J44, J48, J49, J50: 01x02; PinHeader_1x02_P2.54mm_Vertical
JP6, JP7, JP8: Jumper; PinHeader_1x02_P2.54mm_Vertical
R48, R49, R50: 0603; R_0603_1608Metric_Pad0.98x0.95mm_HandSolder

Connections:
GNDREF: JP6.2 (B), JP7.2 (B), JP8.2 (B); also elsewhere on the board
unnamed: J39.2 (Ext), J42.2, J48.2, JP6.1 (A)
unnamed: J39.1 (In), J42.1, R48.1
unnamed: J40.2 (Ext), J43.2, J49.2, JP7.1 (A)
unnamed: J40.1 (In), J43.1, R49.1
unnamed: J41.2 (Ext), J44.2, J50.2, JP8.1 (A)
unnamed: J41.1 (In), J44.1, R50.1
unnamed: J48.1, R48.2
unnamed: J49.1, R49.2
unnamed: J50.1, R50.2

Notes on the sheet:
Notes: 1. The circuits for the RCA connectors are intended for audio and may not be the best choice for video applications.
RCA
Connect to board GND

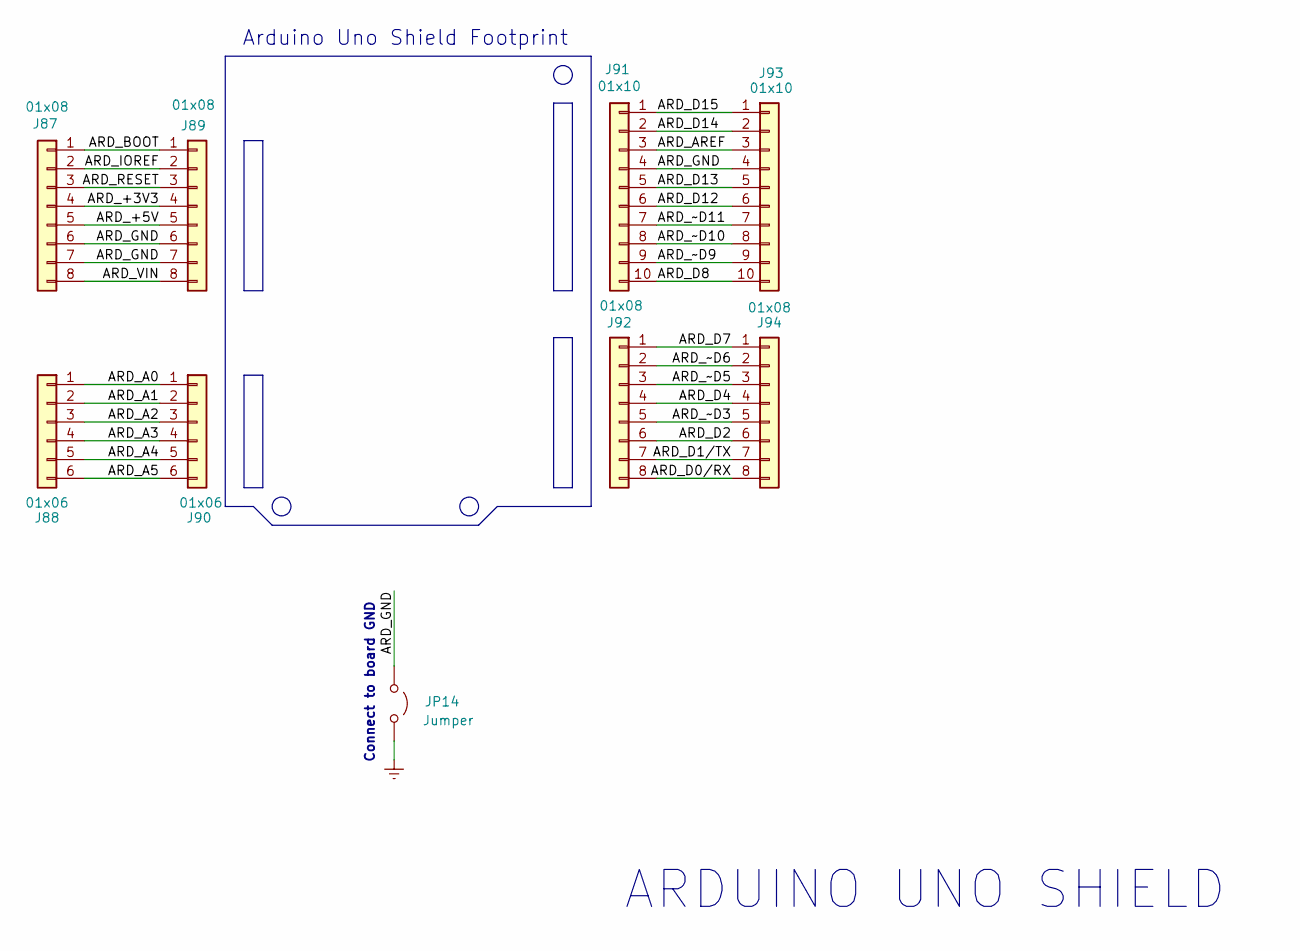
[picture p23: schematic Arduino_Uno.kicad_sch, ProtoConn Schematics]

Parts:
J87, J94: 01x08; PinHeader_1x08_P2.54mm_Vertical
J88: 01x06; PinHeader_1x06_P2.54mm_Vertical
J89, J92: 01x08; PinSocket_1x08_P2.54mm_Vertical
J90: 01x06; PinSocket_1x06_P2.54mm_Vertical
J91: 01x10; PinSocket_1x10_P2.54mm_Vertical
J93: 01x10; PinHeader_1x10_P2.54mm_Vertical
JP14: Jumper; PinHeader_1x02_P2.54mm_Vertical

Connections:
/Arduino Uno/ARD_+3V3: J87.4, J89.4
/Arduino Uno/ARD_+5V: J87.5, J89.5
/Arduino Uno/ARD_A0: J88.1, J90.1
/Arduino Uno/ARD_A1: J88.2, J90.2
/Arduino Uno/ARD_A2: J88.3, J90.3
/Arduino Uno/ARD_A3: J88.4, J90.4
/Arduino Uno/ARD_A4: J88.5, J90.5
/Arduino Uno/ARD_A5: J88.6, J90.6
/Arduino Uno/ARD_AREF: J91.3, J93.3
/Arduino Uno/ARD_BOOT: J87.1, J89.1
/Arduino Uno/ARD_D0/RX: J92.8, J94.8
/Arduino Uno/ARD_D1/TX: J92.7, J94.7
/Arduino Uno/ARD_D2: J92.6, J94.6
/Arduino Uno/ARD_D4: J92.4, J94.4
/Arduino Uno/ARD_D7: J92.1, J94.1
/Arduino Uno/ARD_D8: J91.10, J93.10
/Arduino Uno/ARD_D12: J91.6, J93.6
/Arduino Uno/ARD_D13: J91.5, J93.5
/Arduino Uno/ARD_D14: J91.2, J93.2
/Arduino Uno/ARD_D15: J91.1, J93.1
/Arduino Uno/ARD_GND: J87.6, J87.7, J89.6, J89.7, J91.4, J93.4, JP14.1 (A)
/Arduino Uno/ARD_IOREF: J87.2, J89.2
/Arduino Uno/ARD_RESET: J87.3, J89.3
/Arduino Uno/ARD_VIN: J87.8, J89.8
/Arduino Uno/ARD_~D3: J92.5, J94.5
/Arduino Uno/ARD_~D5: J92.3, J94.3
/Arduino Uno/ARD_~D6: J92.2, J94.2
/Arduino Uno/ARD_~D9: J91.9, J93.9
/Arduino Uno/ARD_~D10: J91.8, J93.8
/Arduino Uno/ARD_~D11: J91.7, J93.7
GNDREF: JP14.2 (B); also elsewhere on the board

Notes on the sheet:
Arduino Uno Shield Footprint
ARDUINO UNO SHIELD
Connect to board GND

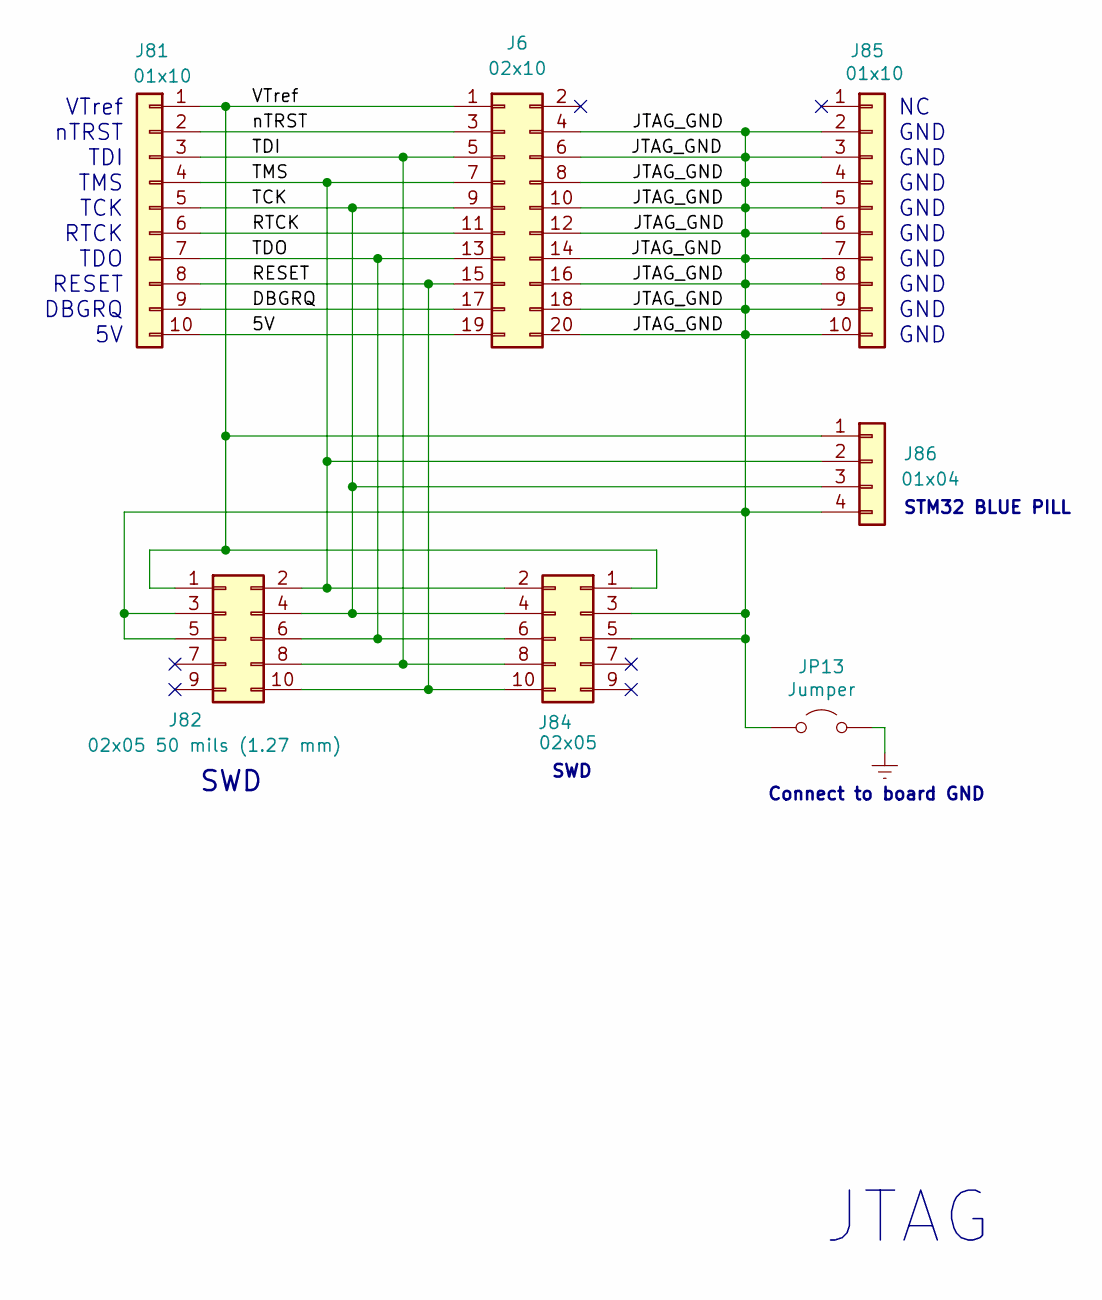
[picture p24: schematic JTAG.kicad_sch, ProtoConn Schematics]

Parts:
J6: 02x10; PinHeader_2x10_P2.54mm_Vertical
J81, J85: 01x10; PinHeader_1x10_P2.54mm_Vertical
J82: 02x05 50 mils (1.27 mm); PinHeader_2x05_P1.27mm_Vertical
J84: 02x05; PinHeader_2x05_P2.54mm_Vertical
J86: 01x04; PinHeader_1x04_P2.54mm_Vertical
JP13: Jumper; PinHeader_1x02_P2.54mm_Vertical

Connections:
/JTAG/5V: J6.19, J81.10
/JTAG/DBGRQ: J6.17, J81.9
/JTAG/JTAG_GND: J6.4, J6.6, J6.8, J6.10, J6.12, J6.14, J6.16, J6.18, J6.20, J82.3, J82.5, J84.3, J84.5, J85.2, J85.3, J85.4, J85.5, J85.6, J85.7, J85.8, J85.9, J85.10, J86.4, JP13.1 (A)
/JTAG/RESET: J6.15, J81.8, J82.10, J84.10
/JTAG/RTCK: J6.11, J81.6
/JTAG/TCK: J6.9, J81.5, J82.4, J84.4, J86.3
/JTAG/TDI: J6.5, J81.3, J82.8, J84.8
/JTAG/TDO: J6.13, J81.7, J82.6, J84.6
/JTAG/TMS: J6.7, J81.4, J82.2, J84.2, J86.2
/JTAG/VTref: J6.1, J81.1, J82.1, J84.1, J86.1
/JTAG/nTRST: J6.3, J81.2
GNDREF: JP13.2 (B); also elsewhere on the board

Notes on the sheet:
STM32 BLUE PILL
SWD
JTAG
VTref nTRST TDI TMS TCK RTCK TDO RESET DBGRQ 5V
Connect to board GND
NC GND GND GND GND GND GND GND GND GND

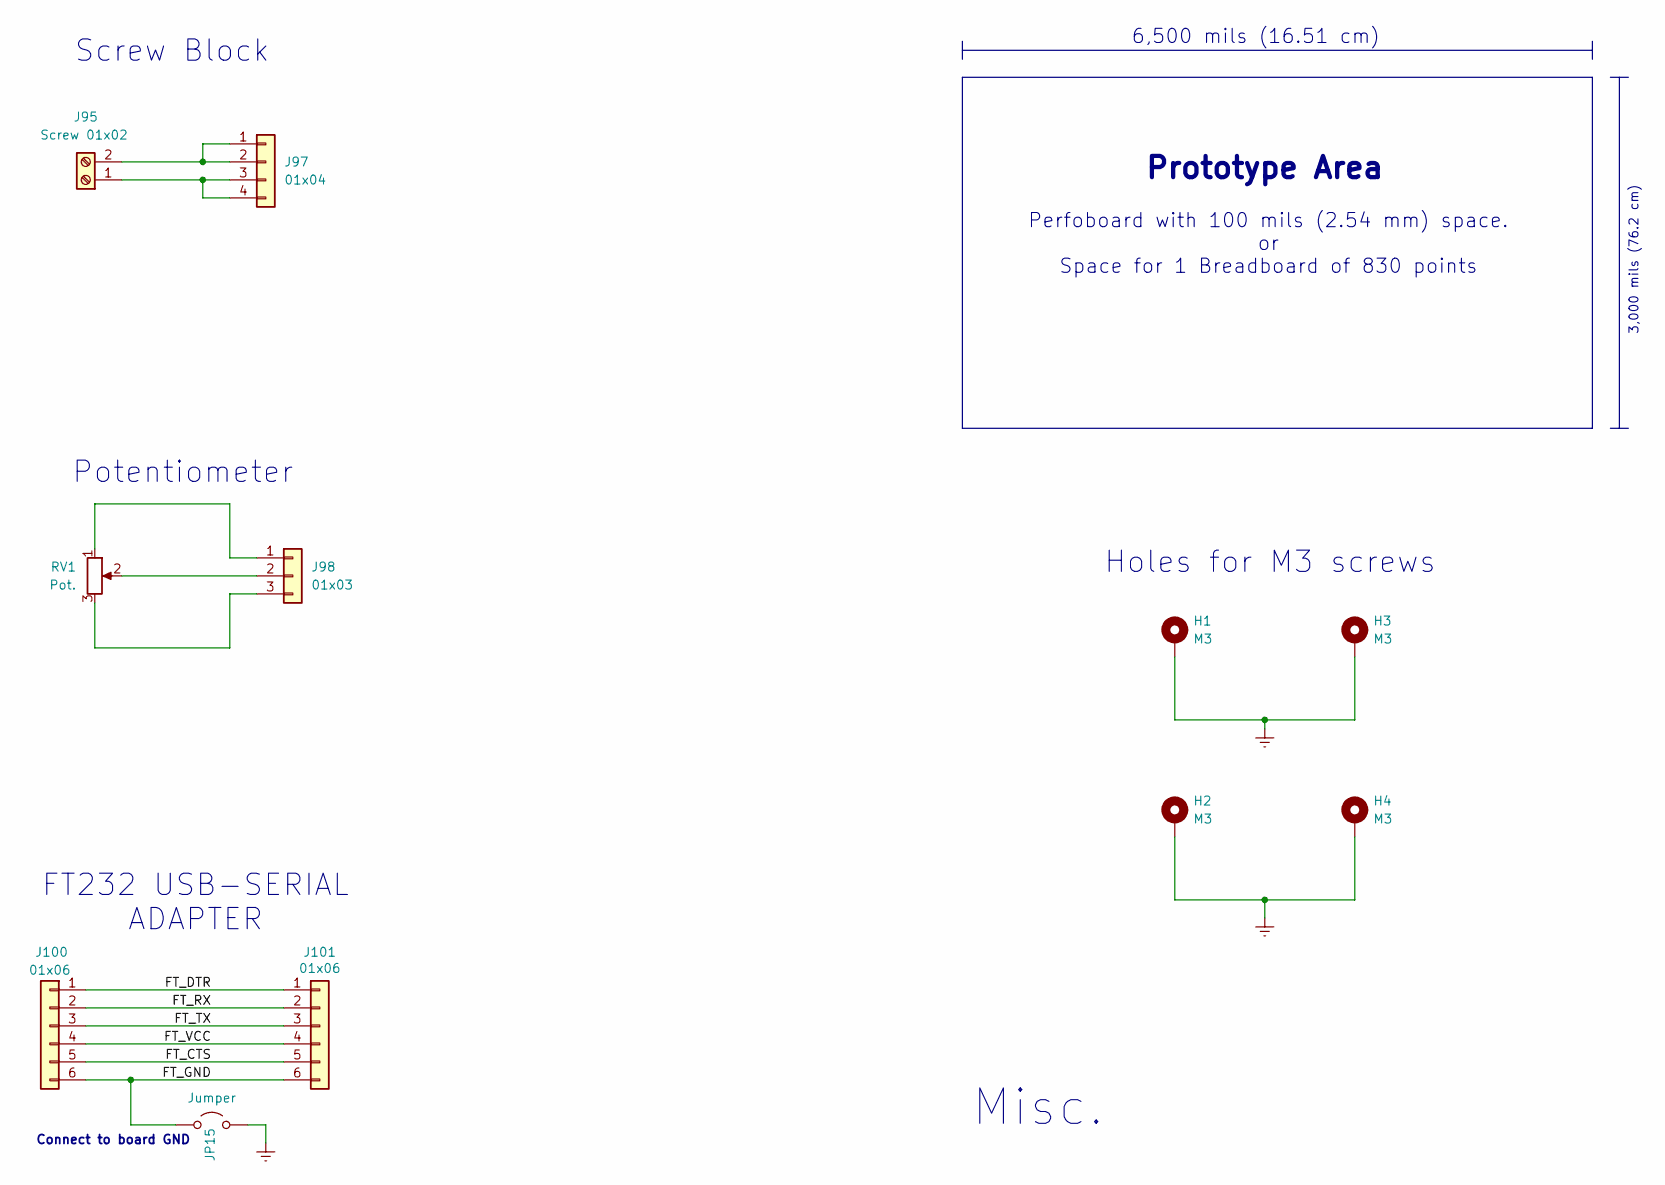
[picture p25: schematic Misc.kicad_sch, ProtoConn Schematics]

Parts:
H1, H2, H3, H4: M3; MountingHole_3.2mm_M3_DIN965_Pad_TopBottom
J95: Screw 01x02; TerminalBlock_bornier-2_P5.08mm
J97: 01x04; PinHeader_1x04_P2.54mm_Vertical
J98: 01x03; PinSocket_1x03_P2.54mm_Vertical
J100, J101: 01x06; PinHeader_1x06_P2.54mm_Vertical
JP15: Jumper; PinHeader_1x02_P2.54mm_Vertical
RV1: Pot.; Potentiometer_Alpha_RD901F-40-00D_Single_Vertical

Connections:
/Misc/FT_CTS: J100.5, J101.5
/Misc/FT_DTR: J100.1, J101.1
/Misc/FT_GND: J100.6, J101.6, JP15.1 (A)
/Misc/FT_RX: J100.2, J101.2
/Misc/FT_TX: J100.3, J101.3
/Misc/FT_VCC: J100.4, J101.4
GNDREF: H1.1, H2.1, H3.1, H4.1, JP15.2 (B); also elsewhere on the board
unnamed: J95.1, J97.3, J97.4
unnamed: J95.2, J97.1, J97.2
unnamed: J98.1, RV1.1
unnamed: J98.2, RV1.2
unnamed: J98.3, RV1.3

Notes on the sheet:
Connect to board GND
6,500 mils (16.51 cm)
Misc.
Screw Block
Perfoboard with 100 mils (2.54 mm) space. or Space for 1 Breadboard of 830 points
Holes for M3 screws
Potentiometer
Prototype Area
3,000 mils (76.2 cm)
FT232 USB-SERIAL ADAPTER

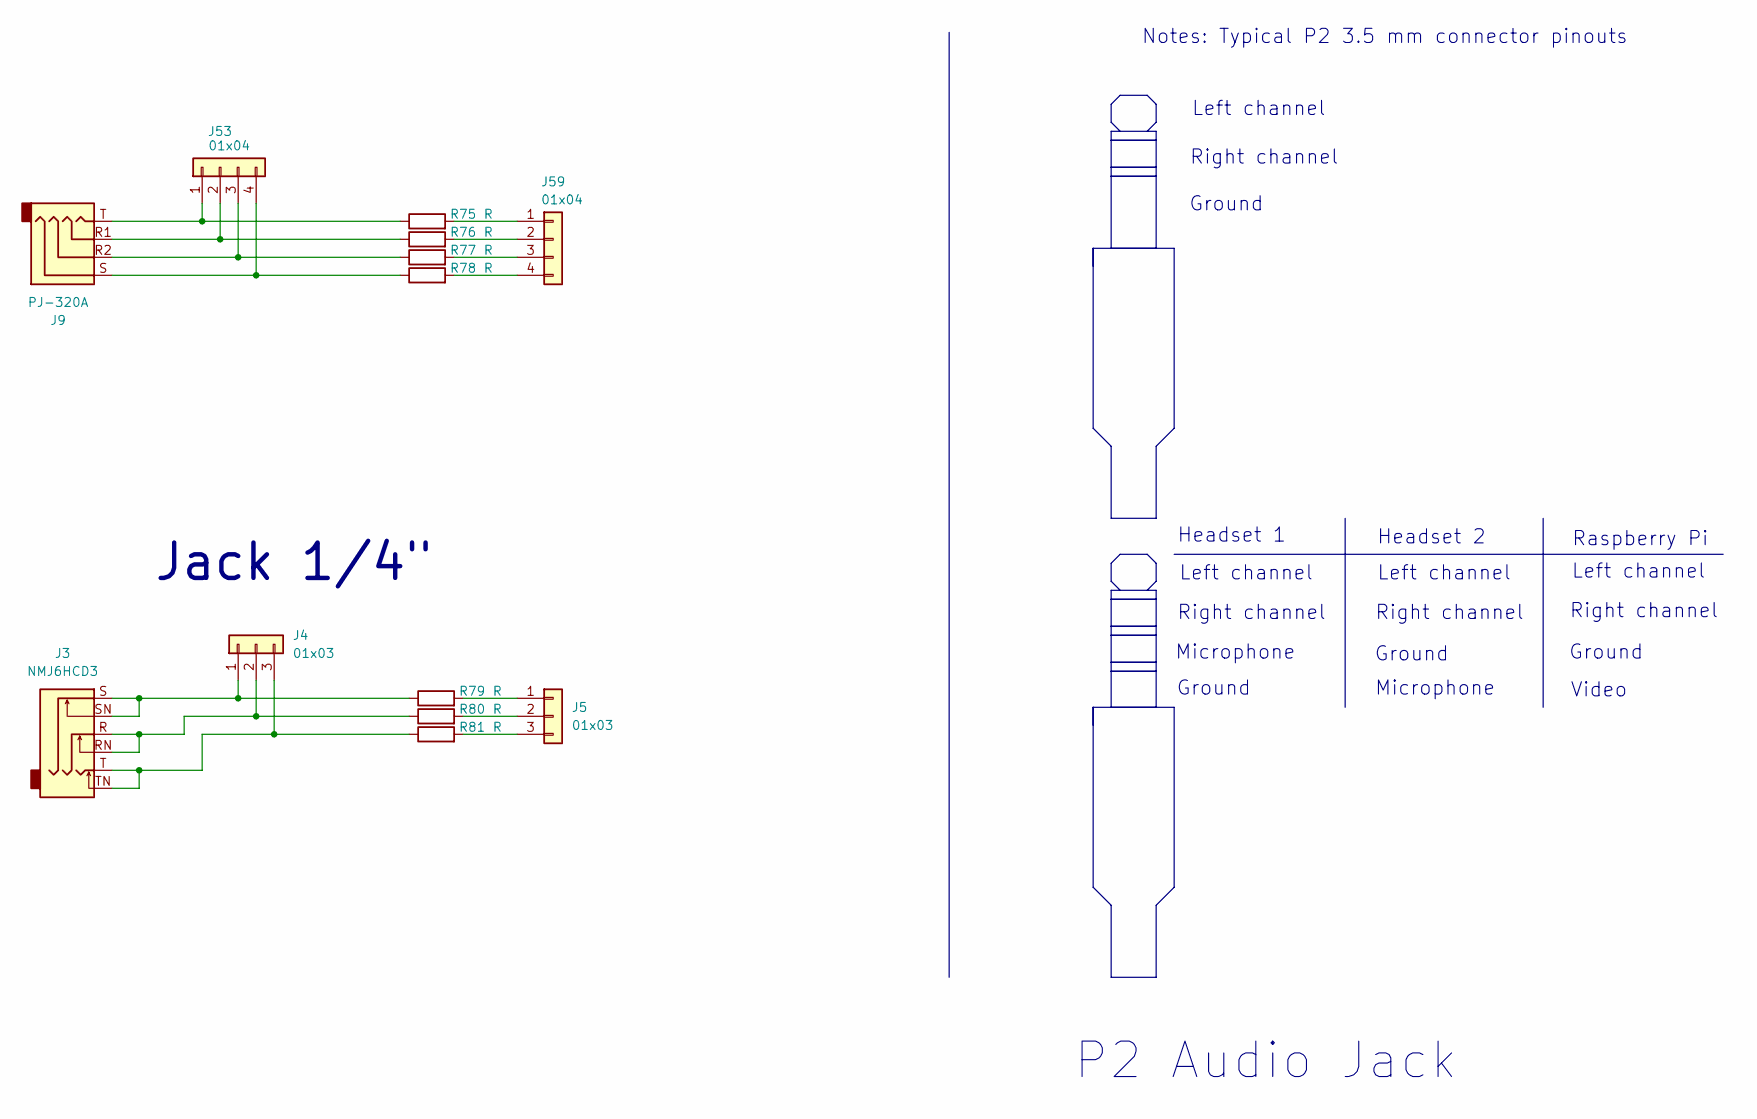
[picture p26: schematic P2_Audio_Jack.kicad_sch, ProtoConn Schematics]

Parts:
J3: NMJ6HCD3; Jack_6.35mm_Neutrik_NMJ6HCD3_Horizontal
J4, J5: 01x03; PinSocket_1x03_P2.54mm_Vertical
J9: PJ-320A
J53, J59: 01x04; PinHeader_1x04_P2.54mm_Vertical
R75, R76, R77, R78, R79, R80, R81: R; R_0603_1608Metric_Pad0.98x0.95mm_HandSolder

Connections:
unnamed: J3.S, J3.SN, J4.1, R79.1
unnamed: J3.R, J3.RN, J4.2, R80.1
unnamed: J3.T, J3.TN, J4.3, R81.1
unnamed: J5.1, R79.2
unnamed: J5.2, R80.2
unnamed: J5.3, R81.2
unnamed: J9.T, J53.1, R75.1
unnamed: J9.R1, J53.2, R76.1
unnamed: J9.R2, J53.3, R77.1
unnamed: J9.S, J53.4, R78.1
unnamed: J59.1, R75.2
unnamed: J59.2, R76.2
unnamed: J59.3, R77.2
unnamed: J59.4, R78.2

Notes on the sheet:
Ground
Notes: Typical P2 3.5 mm connector pinouts
Left channel
Microphone
Right channel
Jack 1/4"
P2 Audio Jack
Raspberry Pi
Video
Headset 1
Headset 2

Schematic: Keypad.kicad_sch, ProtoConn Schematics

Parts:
J36: 01x02; PinHeader_1x02_P2.54mm_Vertical
J37: 01x04; PinHeader_1x04_P2.54mm_Vertical
J38: 01x03; PinSocket_1x03_P2.54mm_Vertical
R39, R40, R41: 0603; R_0603_1608Metric_Pad0.98x0.95mm_HandSolder
SW3, SW4, SW5, SW6, SW7, SW8, SW9, SW10, SW11, SW12, SW13, SW14: SW_Push_45deg; SW_PUSH_6mm

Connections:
unnamed: J36.1, J36.2, R39.1, R40.1, R41.1
unnamed: J37.1, SW3.1, SW7.1, SW11.1
unnamed: J37.2, SW4.1, SW8.1, SW12.1
unnamed: J37.3, SW5.1, SW9.1, SW13.1
unnamed: J37.4, SW6.1, SW10.1, SW14.1
unnamed: J38.1, R39.2, SW11.2, SW12.2, SW13.2, SW14.2
unnamed: J38.2, R40.2, SW7.2, SW8.2, SW9.2, SW10.2
unnamed: J38.3, R41.2, SW3.2, SW4.2, SW5.2, SW6.2

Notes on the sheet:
COL1 COL2 COL3
R1 R2 R3 R4
Notes: 1. The resistors are for pull-up or pull-down purposes as needed.
Keypad

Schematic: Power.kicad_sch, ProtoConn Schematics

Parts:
C1, C5: C; CP_Radial_D5.0mm_P2.50mm
C3, C7: C 0603; C_0603_1608Metric_Pad1.08x0.95mm_HandSolder
D1: LED; LED_0603_1608Metric
J26: Barrel Jack; BarrelJack_Kycon_KLDX-0202-xC_Horizontal
J28: Screw 01x02; TerminalBlock_bornier-2_P5.08mm
J30: 01x02; PinHeader_1x02_P2.54mm_Vertical
J32: 02x04; PinHeader_2x04_P2.54mm_Vertical
J34: 01x06; PinHeader_1x06_P2.54mm_Vertical
R37: 0603; R_0603_1608Metric_Pad0.98x0.95mm_HandSolder
SW1: SW_SPDT; SW_Slide_SPDT_Straight_CK_OS102011MS2Q
U1: LM78XX TO220; TO-220-3_Vertical

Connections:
GNDREF: C1.2, C3.2, C5.2, C7.2, J26.2, J26.3, J28.1, J30.2, J32.1, J32.3, J32.5, J32.7, J34.4, J34.5, J34.6, R37.2, U1.2 (GND); also elsewhere on the board
unnamed: C1.1, C3.1, D1.2 (A), SW1.1 (A), U1.1 (VI)
unnamed: D1.1 (K), R37.1
unnamed: J26.1, J28.2, J30.1, SW1.2 (B)
unnamed: J32.2, J32.4, J32.6, J32.8, SW1.3 (C)
unnamed: C5.1, C7.1, J34.1, J34.2, J34.3, U1.3 (VO)

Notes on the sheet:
Notes: 1. Barrel Jack connected for center positive power supply.
POWER
+ V GND

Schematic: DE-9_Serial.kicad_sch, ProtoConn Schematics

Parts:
J22: 01x04; PinHeader_1x04_P2.54mm_Vertical
J23: DE9; DSUB-9_Female_Horizontal_P2.77x2.84mm_EdgePinOffset4.94mm_H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
J24: 01x09; PinHeader_1x09_P2.54mm_Vertical
J25: 01x06; PinHeader_1x06_P2.54mm_Vertical
JP5: Jumper; PinHeader_1x02_P2.54mm_Vertical
R35, R36: 0603; R_0603_1608Metric_Pad0.98x0.95mm_HandSolder

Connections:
GNDREF: JP5.1 (A); also elsewhere on the board
unnamed: J22.1, J23.1, J24.1, R35.2
unnamed: J22.2, J23.6, J24.6
unnamed: J22.3, J23.8, J24.8, R35.1
unnamed: J22.4, J23.5, J24.5, J25.5
unnamed: J23.0 (PAD), JP5.2 (B)
unnamed: J23.2, J24.2, J25.1, R36.2
unnamed: J23.3, J24.3, J25.2
unnamed: J23.4, J24.4, J25.4
unnamed: J23.7, J24.7, J25.3, R36.1
unnamed: J23.9, J24.9, J25.6

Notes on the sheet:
CAN Low GND CAN High SHIELD
Notes: 1. The resistors are for CAN termination or can be left unmounted, depending on the application. 2. The DE9 connector will be male or female based on the application requirements. 3. The markings are for the most common types of communication interfaces and may vary for other applications.
GND CTS+ RTS+ RXD+ RXD- CTS- RTS- TXD+ TXD-
RS422 - RS485
RS232
DCD RXD TXD DTR GND DSR RTS CTS RI
Connect to board GND
CAN Low GND CAN High SP SHIELD VB+
CAN 1
DE-9 Serial
CAN 2

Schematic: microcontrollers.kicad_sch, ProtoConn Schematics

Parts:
J61, J63, J69, J73: 01x12; PinHeader_1x12_P2.54mm_Vertical
J62, J68, J70, J71: 01x10; PinHeader_1x10_P2.54mm_Vertical
J64, J66: 01x12; PinSocket_1x12_P2.54mm_Vertical
J65, J67: 01x10; PinSocket_1x10_P2.54mm_Vertical
J72, J74, J75: 01x20; PinSocket_1x20_P2.54mm_Vertical

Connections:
/Microcontrollers/uc_pin1: J61.1, J63.1, J64.1
/Microcontrollers/uc_pin2: J61.2, J63.2, J64.2
/Microcontrollers/uc_pin3: J61.3, J63.3, J64.3
/Microcontrollers/uc_pin4: J61.4, J63.4, J64.4
/Microcontrollers/uc_pin5: J61.5, J63.5, J64.5
/Microcontrollers/uc_pin6: J61.6, J63.6, J64.6
/Microcontrollers/uc_pin7: J61.7, J63.7, J64.7
/Microcontrollers/uc_pin8: J61.8, J63.8, J64.8
/Microcontrollers/uc_pin9: J61.9, J63.9, J64.9
/Microcontrollers/uc_pin10: J61.10, J63.10, J64.10
/Microcontrollers/uc_pin11: J61.11, J63.11, J64.11
/Microcontrollers/uc_pin12: J61.12, J63.12, J64.12
/Microcontrollers/uc_pin13: J62.1, J65.1, J68.1
/Microcontrollers/uc_pin14: J62.2, J65.2, J68.2
/Microcontrollers/uc_pin15: J62.3, J65.3, J68.3
/Microcontrollers/uc_pin16: J62.4, J65.4, J68.4
/Microcontrollers/uc_pin17: J62.5, J65.5, J68.5
/Microcontrollers/uc_pin18: J62.6, J65.6, J68.6
/Microcontrollers/uc_pin19: J62.7, J65.7, J68.7
/Microcontrollers/uc_pin20: J62.8, J65.8, J68.8
/Microcontrollers/uc_pin21: J62.9, J65.9, J68.9
/Microcontrollers/uc_pin22: J62.10, J65.10, J68.10
/Microcontrollers/uc_pin23: J67.10, J70.10, J71.10, J72.20, J74.20, J75.20
/Microcontrollers/uc_pin24: J67.9, J70.9, J71.9, J72.19, J74.19, J75.19
/Microcontrollers/uc_pin25: J67.8, J70.8, J71.8, J72.18, J74.18, J75.18
/Microcontrollers/uc_pin26: J67.7, J70.7, J71.7, J72.17, J74.17, J75.17
/Microcontrollers/uc_pin27: J67.6, J70.6, J71.6, J72.16, J74.16, J75.16
/Microcontrollers/uc_pin28: J67.5, J70.5, J71.5, J72.15, J74.15, J75.15
/Microcontrollers/uc_pin29: J67.4, J70.4, J71.4, J72.14, J74.14, J75.14
/Microcontrollers/uc_pin30: J67.3, J70.3, J71.3, J72.13, J74.13, J75.13
/Microcontrollers/uc_pin31: J67.2, J70.2, J71.2, J72.12, J74.12, J75.12
/Microcontrollers/uc_pin32: J67.1, J70.1, J71.1, J72.11, J74.11, J75.11
/Microcontrollers/uc_pin33: J66.12, J69.12, J72.10, J73.12, J74.10, J75.10
/Microcontrollers/uc_pin34: J66.11, J69.11, J72.9, J73.11, J74.9, J75.9
/Microcontrollers/uc_pin35: J66.10, J69.10, J72.8, J73.10, J74.8, J75.8
/Microcontrollers/uc_pin36: J66.9, J69.9, J72.7, J73.9, J74.7, J75.7
/Microcontrollers/uc_pin37: J66.8, J69.8, J72.6, J73.8, J74.6, J75.6
/Microcontrollers/uc_pin38: J66.7, J69.7, J72.5, J73.7, J74.5, J75.5
/Microcontrollers/uc_pin39: J66.6, J69.6, J72.4, J73.6, J74.4, J75.4
/Microcontrollers/uc_pin40: J66.5, J69.5, J72.3, J73.5, J74.3, J75.3
/Microcontrollers/uc_pin41: J66.4, J69.4, J72.2, J73.4, J74.2, J75.2
/Microcontrollers/uc_pin42: J66.3, J69.3, J72.1, J73.3, J74.1, J75.1
/Microcontrollers/uc_pin43: J66.2, J69.2, J73.2
/Microcontrollers/uc_pin44: J66.1, J69.1, J73.1

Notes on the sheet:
ESP32
Raspberry Pi Pico
STM32 Pill and Arduino mini Pro
Microcontrollers connectors
Adafruit Feather
Up to 40 Pins 600 mils (15.24 mm) Up to 40 pins 700 mils (17.78 mm)
Up to 44 pins 1" (25.4 mm)
Up to 40 Pins 800 mils (20,32 mm)

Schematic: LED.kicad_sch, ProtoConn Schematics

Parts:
D3, D4, D5, D6, D7, D8, D9, D10: LED; LED_0603_1608Metric
J51: 01x02; PinHeader_1x02_P2.54mm_Vertical
J52: Conn_01x08; PinHeader_1x08_P2.54mm_Vertical
JP9: Jumper; PinHeader_1x02_P2.54mm_Vertical
R51, R52, R53, R54, R55, R56, R57, R58: 0603; R_0603_1608Metric_Pad0.98x0.95mm_HandSolder

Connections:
GNDREF: JP9.2 (B); also elsewhere on the board
unnamed: D3.2 (A), J52.1
unnamed: D3.1 (K), R51.2
unnamed: D4.2 (A), J52.2
unnamed: D4.1 (K), R52.1
unnamed: D5.2 (A), J52.3
unnamed: D5.1 (K), R53.1
unnamed: D6.2 (A), J52.4
unnamed: D6.1 (K), R54.2
unnamed: D7.2 (A), J52.5
unnamed: D7.1 (K), R55.1
unnamed: D8.2 (A), J52.6
unnamed: D8.1 (K), R56.1
unnamed: D9.2 (A), J52.7
unnamed: D9.1 (K), R57.2
unnamed: D10.2 (A), J52.8
unnamed: D10.1 (K), R58.1
unnamed: J51.1, J51.2, JP9.1 (A), R51.1, R52.2, R53.2, R54.1, R55.2, R56.2, R57.1, R58.2

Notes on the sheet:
Notes: 1. The LEDs are connected as common cathode. To switch to common anode, the LEDs need to be reversed.
Connect to board GND
LED

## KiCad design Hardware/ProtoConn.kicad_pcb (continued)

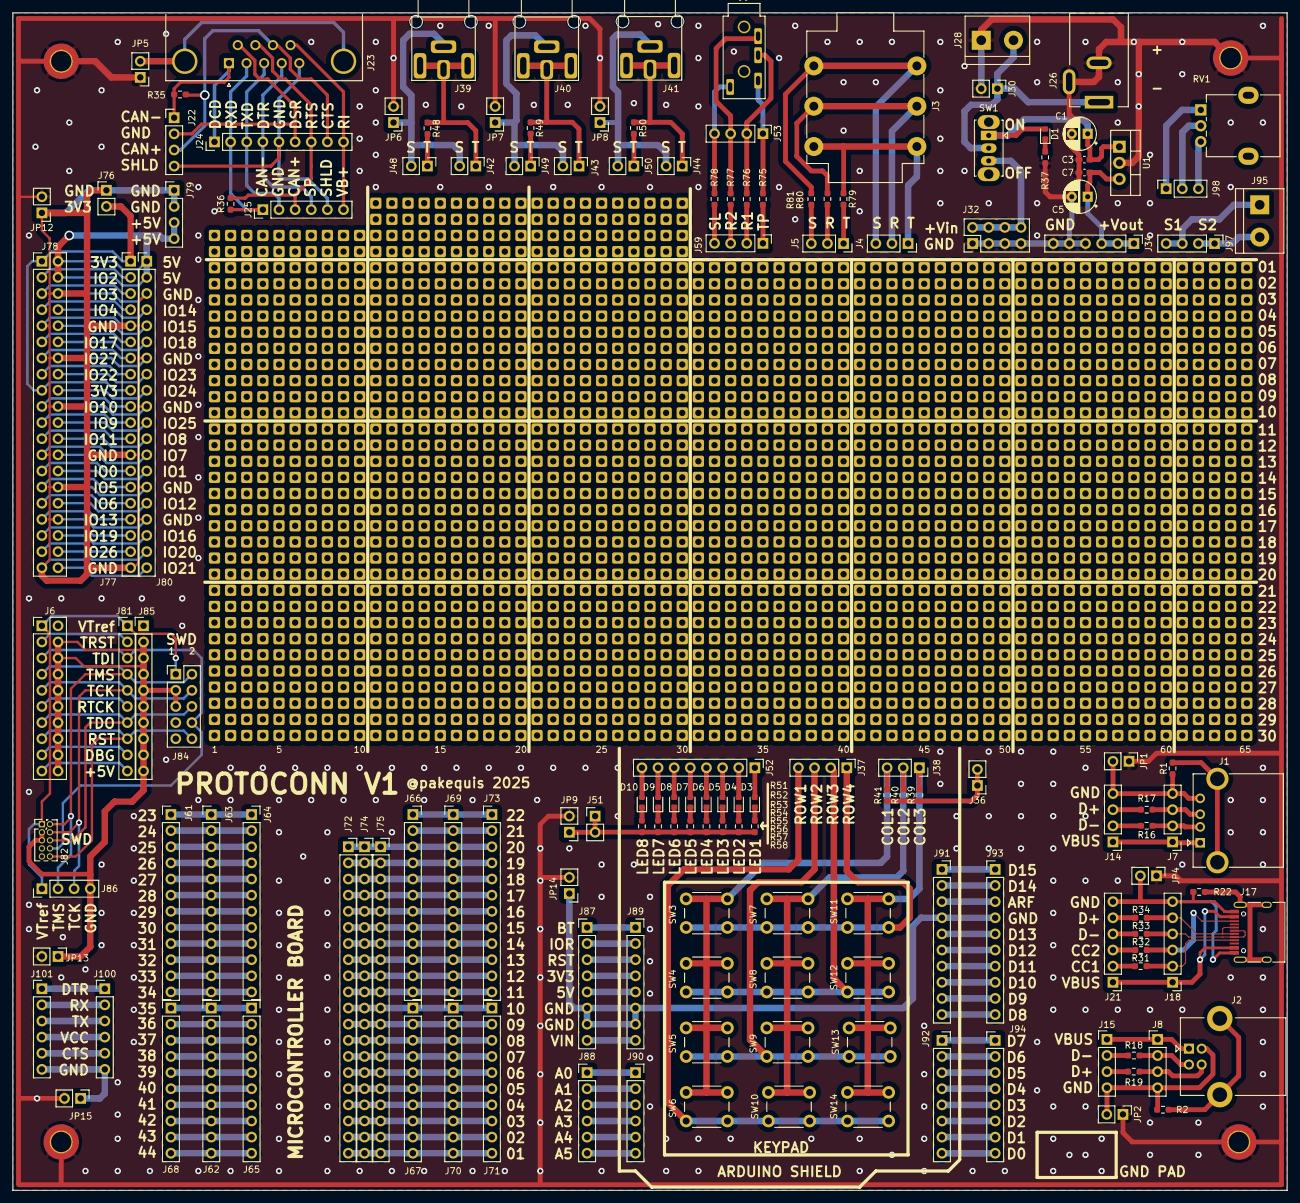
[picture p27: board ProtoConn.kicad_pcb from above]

Board: 2 copper layers, 200.7 x 185.4 mm, 156 parts (0 on the bottom side), 216 nets.

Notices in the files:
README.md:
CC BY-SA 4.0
